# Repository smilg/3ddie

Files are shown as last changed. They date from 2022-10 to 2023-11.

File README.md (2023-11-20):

# 3ddie
3D Digital Interface, EPIC!

## Project Structure
[3ddie/](3ddie/): contains the Kicad (6.x) project for 3ddie. This includes the schematic, board layout, [BOM](3ddie/3ddie-bom-cleaned.csv), symbols, and footprints.

[mcad/](mcad/): contains SOLIDWORKS assembly files for 3ddie and the beginnings of a case.

[firmware/](firmware/): contains firmware for 3ddie. Currently, this only includes the start of the I²C to USB bridge firmware for the RP2040 to allow connection between the MGC3130 and Microchip's Aurea software. The submodules in that folder are projects that we are basing this off of.

[silkscreen_images/](silkscreen_images/): contains the image files for the silkscreen art on the PCB. These were converted to footprints using Kicad's built-in tool.

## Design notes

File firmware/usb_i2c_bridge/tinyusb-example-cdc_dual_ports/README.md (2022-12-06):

This is example code from the [TinyUSB project](https://github.com/hathach/tinyusb) created by hathach. It's located in [/examples/device/cdc_dual_ports](https://github.com/hathach/tinyusb/tree/master/examples/device/cdc_dual_ports).

It should be useful for seeing how to create our own CDC driver for communicating with Aurea.

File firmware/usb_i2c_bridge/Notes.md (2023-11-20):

# I/O Pin Setup
|Name |GPIO #|Pkg #|Config |
|:---:|:----:|:---:|:---:|
|MCLR |29 |41 |Out PU |
|TS (EIO0)|14 |17 |In/Out |
|SDA (SI0)|12 |15 |I2C_SDA (i2c0)|
|SCL (SI1)|13 |16 |I2C_SCL (i2c0)|

# rp2040 i2c interface notes
## functions
### int main(void): setup stuff
* call board_init() - pico SDK function
* call tusb_init() - for tinyusb stuff
* set gpio pin modes, initialize i2c
* infinite loop tud_task() - for tinyusb

### void tud_mount_cb(void): invoked when device is mounted
* empty

### void tud_umount_cb(void): invoked when device is unmounted
* empty

### void tud_suspend_cb(bool remote_wakeup_en): invoked when usb bus is suspended
* empty

### void tud_resume_cb(void): invoked when usb bus is resumed
* empty

# gestic.c notes

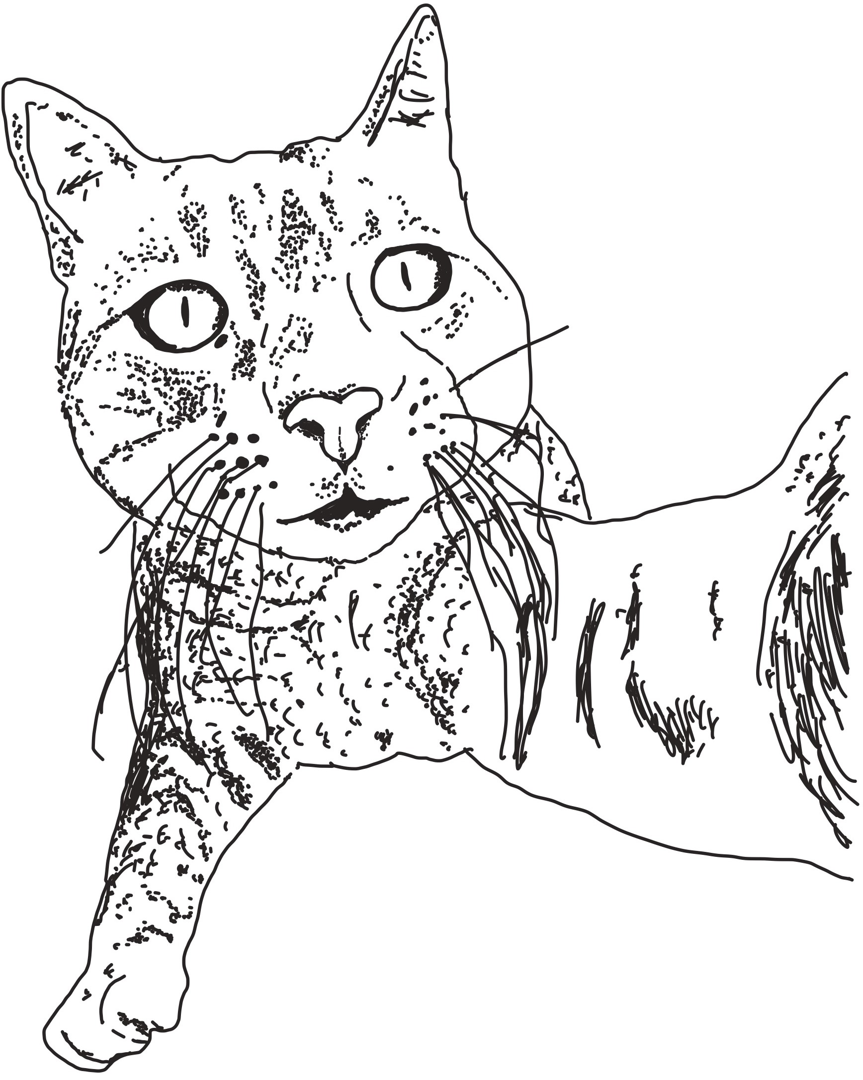
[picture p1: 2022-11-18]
silkscreen_images/cat_crop.JPG

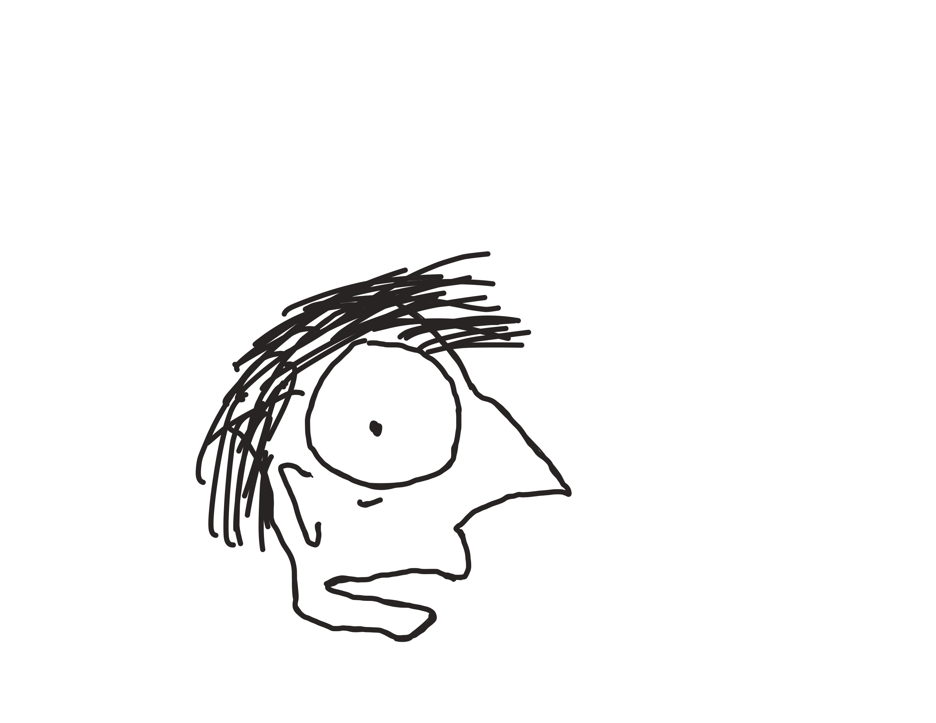
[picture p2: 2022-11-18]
silkscreen_images/grant.JPG

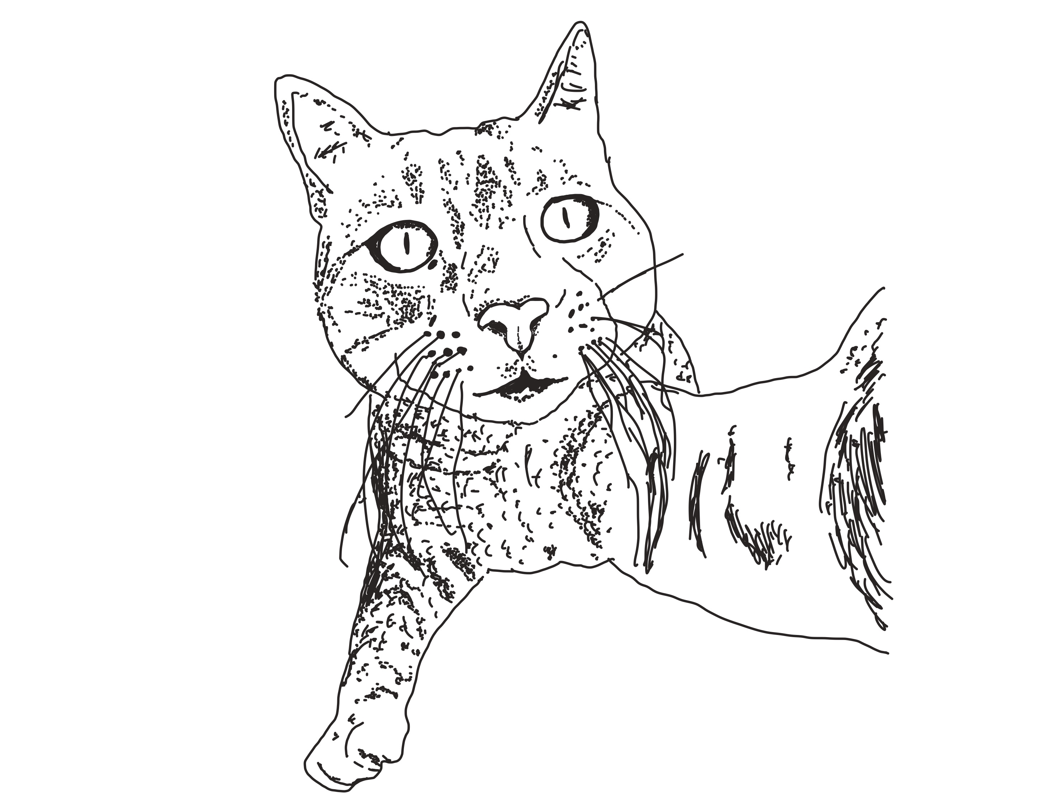
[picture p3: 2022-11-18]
silkscreen_images/cat.JPG

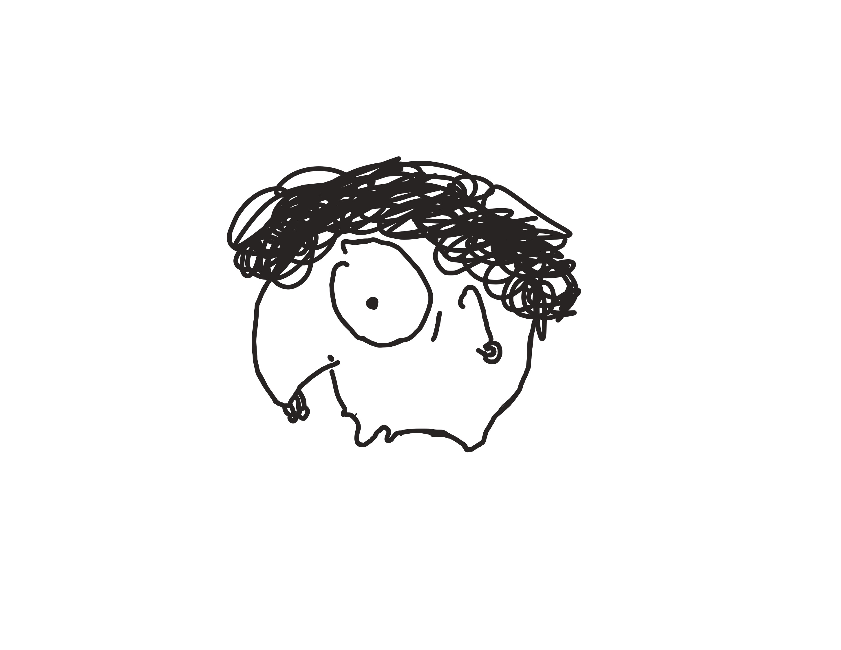
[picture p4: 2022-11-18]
silkscreen_images/max.JPG

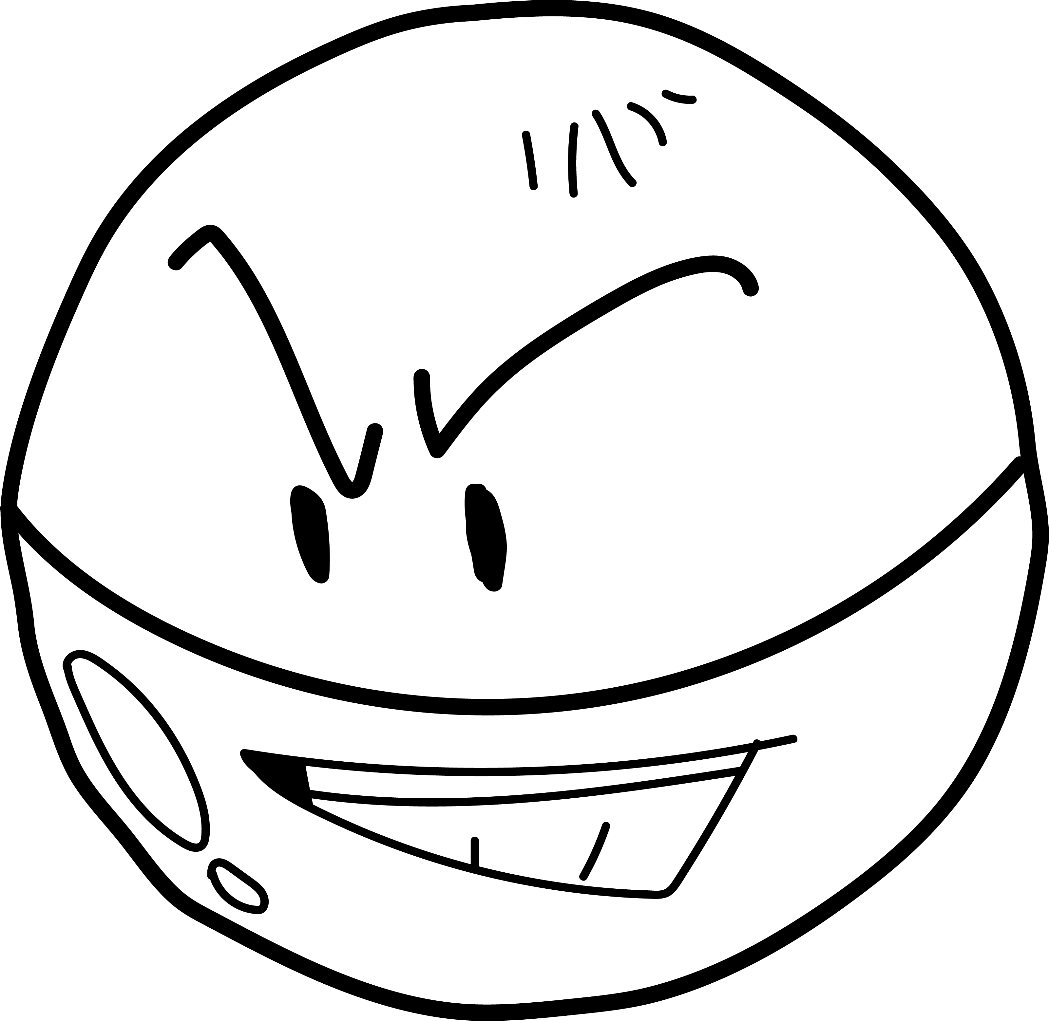
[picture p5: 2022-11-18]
silkscreen_images/electrode.png

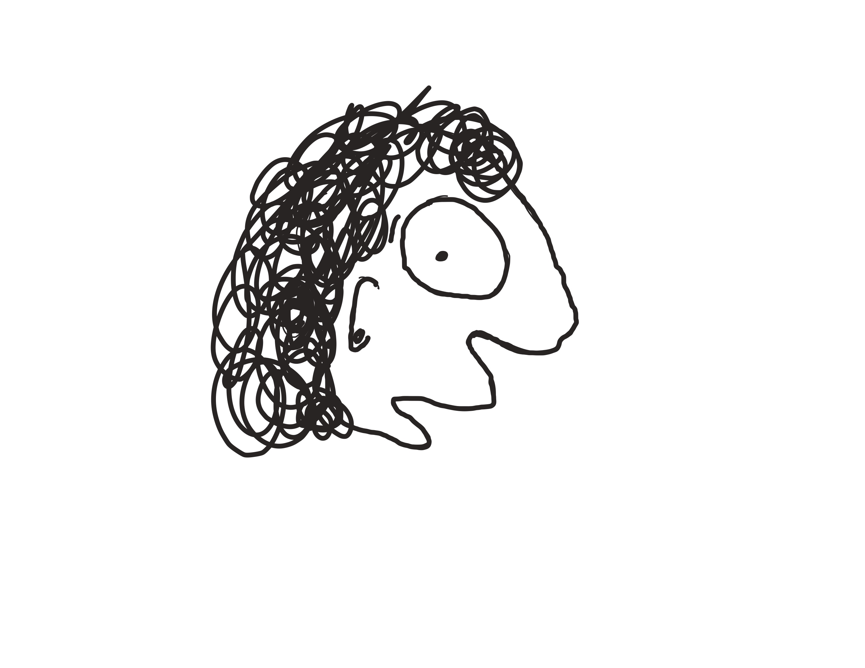
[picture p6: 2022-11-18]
silkscreen_images/smilg.JPG

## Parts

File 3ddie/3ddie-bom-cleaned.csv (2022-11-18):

Collated Components:
Item | Qty | Reference(s) | Value | Digikey Catalog # | Manufacturer Part # | MP3 Part | LibPart | Footprint | Datasheet
1 | 3 | C1, C14, C18 | 0.1?F | 1276-1033-1-ND | CL10B104JB8NNNC | Y | Device:C | Capacitor_SMD:C_0603_1608Metric | ~
2 | 8 | C2, C3, C4, C5, C6, C7, C10, C11 | 0.1?F | 1292-1366-1-ND | 0402X104K500CT | Y | Device:C | Capacitor_SMD:C_0402_1005Metric | ~
3 | 2 | C8, C9 | 1.0?F | 1276-6796-1-ND | CL05A105KL5NRNC | Y | Device:C | Capacitor_SMD:C_0402_1005Metric | ~
4 | 2 | C12, C13 | 10µF | 490-18214-1-ND | GRM188R61E106KA73D | Y | Device:C | Capacitor_SMD:C_0603_1608Metric | ~
5 | 1 | C15 | 2.2?F | 490-10731-1-ND | GRM188R61E225KA12D | N | Device:C | Capacitor_SMD:C_0603_1608Metric | ~
6 | 2 | C16, C17 | 4.7?F | 490-7203-1-ND | GRM188R61E475KE11D | N | Device:C | Capacitor_SMD:C_0603_1608Metric | ~
7 | 1 | C19 | 1.0?F | 1276-1184-1-ND | CL10B105KA8NNNC | Y | Device:C_Small | Capacitor_SMD:C_0603_1608Metric | ~
8 | 1 | C20 | 0.1?F | 1276-1033-1-ND | CL10B104JB8NNNC | Y | Device:C_Small | Capacitor_SMD:C_0603_1608Metric | ~
9 | 1 | D1 | LED | 160-1887-1-ND | LTST-C170TGKT | Y | Device:LED_Filled | LED_SMD:LED_0805_2012Metric | ~
10 | 1 | D2 | PWR | 160-1427-1-ND | LTST-C171KRKT | Y | Device:LED_Filled | LED_SMD:LED_0805_2012Metric | ~
11 | 1 | D3 | 1N4148WT | 1N4148WTCT-ND | 1N4148WT | N | Diode:1N4148WT | Diode_SMD:D_SOD-523 | https://rocelec.widen.net/view/pdf/bnxdzepaue/ONSM-S-A0003584797-1.pdf?t.download=true&u=5oefqw
12 | 1 | J1 | USB4105-GF-A | 2073-USB4105-GF-ACT-ND | USB4105-GF-A | Y | Eclectronics:USB4105-GF-A | Eclectronics:USB4105-GF-A
13 | 1 | J2 | TRS_MIDI_IN | CP1-3533NG-ND | SJ1-3533NG | N | Connector:AudioJack3 | Connector_Audio:Jack_3.5mm_CUI_SJ1-3533NG_Horizontal | https://www.cuidevices.com/product/resource/sj1-353xng.pdf
14 | 1 | J3 | TRS_MIDI_OUT | CP1-3533NG-ND | SJ1-3533NG | N | Connector:AudioJack3 | Connector_Audio:Jack_3.5mm_CUI_SJ1-3533NG_Horizontal | https://www.cuidevices.com/product/resource/sj1-353xng.pdf
15 | 1 | J4 | Conn_02x15_Odd_Even | 2057-BHR-30-HUA-ND | BHR-30-HUA | N | Connector_Generic:Conn_02x15_Odd_Even | Connector_IDC:IDC-Header_2x15_P2.54mm_Horizontal | https://app.adam-tech.com/products/download/data_sheet/203217/bhr-xx-hua-data-sheet.pdf
16 | 4 | R1, R2, R3, R4 | 5.1K? | P5.10KHCT-ND | ERJ-3EKF5101V | Y | Device:R | Resistor_SMD:R_0603_1608Metric | ~
17 | 2 | R5, R6 | 27? | P27.0LCT-ND | ERJ-2RKF27R0X | Y | Device:R | Resistor_SMD:R_0402_1005Metric | ~
18 | 2 | R7, R12 | 1K? | 311-1.00KHRCT-ND | RC0603FR-071KL | Y | Device:R | Resistor_SMD:R_0603_1608Metric | ~
19 | 5 | R8, R9, R10, R11, R13 | 10K? | CR0603-FX-1002ELFCT-ND | CR0603-FX-1002ELF | N | Device:R | Resistor_SMD:R_0603_1608Metric | ~
20 | 2 | R14, R15 | 1.8K? | 311-1.80KHRCT-ND | RC0603FR-071K8L | N | Device:R | Resistor_SMD:R_0603_1608Metric | ~
21 | 1 | R16 | 220? | 311-220HRCT-ND | RC0603FR-07220RL | N | Device:R | Resistor_SMD:R_0603_1608Metric | ~
22 | 1 | R17 | 10? | 13-RC0603FR-1010RLCT-ND | RC0603FR-1010RL | N | Device:R | Resistor_SMD:R_0603_1608Metric | ~
23 | 1 | R18 | 33? | 311-33.0HRCT-ND | RC0603FR-0733RL | N | Device:R | Resistor_SMD:R_0603_1608Metric | ~
24 | 1 | R19 | 4.7K? | 311-4.70KHRCT-ND | RC0603FR-074K7L | N | Device:R_Small | Resistor_SMD:R_0603_1608Metric | ~
25 | 2 | RV1, RV2 | 10K | PDB12-H4251-103BF-ND | PDB12-H4251-103BF | N | Device:R_Potentiometer | 3ddie:PDB12-H4251-103BF | https://www.bourns.com/docs/Product-Datasheets/PDB12.pdf
26 | 1 | S1 | RST | EG4374CT-ND | TL3301AF160QJ | Y | Eclectronics:SW | Eclectronics:TL3301AFxxxxJ | https://www.ckswitches.com/media/1465/kxt3.pdf
27 | 1 | S2 | BOOT | EG4374CT-ND | TL3301AF160QJ | Y | Eclectronics:SW | Eclectronics:TL3301AFxxxxJ | https://www.ckswitches.com/media/1465/kxt3.pdf
28 | 1 | U1 | W25Q128JV | W25Q128JVPIMCT-ND | W25Q128JVPIM TR | Y | Eclectronics:W25Q128JV | Eclectronics:MIC_WSON-8 | https://www.winbond.com/resource-files/w25q128jv_dtr%20revc%2003272018%20plus.pdf
29 | 1 | U2 | RP2040 | 2648-SC0914(13)CT-ND | SC0914(13) | Y | Eclectronics:RP2040 | Eclectronics:RP2040 | https://datasheets.raspberrypi.com/rp2040/rp2040-datasheet.pdf
30 | 1 | U3 | MCP1702T-3302E_CB | MCP1702T-3302E/CBCT-ND | MCP1702T-3302E/CB | Y | Eclectronics:MCP1702T-3302E_CB | Package_TO_SOT_SMD:SOT-23 | https://ww1.microchip.com/downloads/en/DeviceDoc/22008E.pdf
31 | 1 | U4 | MGC3130-I/MQ | MGC3130-I/MQ-ND | MGC3130-I/MQ | N | :MGC3130-I{brace}slash}MQ_1 | 3ddie:MGC3130T-I_MQ | https://ww1.microchip.com/downloads/en/DeviceDoc/MGC3030-3130-3D-Tracking-and-Gesture-Controller-40001667F.pdf
32 | 1 | U5 | MCP1416R | MCP1416RT-E/OTCT-ND | MCP1416RT-E/OT | N | Driver_FET:MCP1416R | Package_TO_SOT_SMD:SOT-23-5 | http://ww1.microchip.com/downloads/en/DeviceDoc/20002092F.pdf
33 | 1 | U6 | 6N137 | 6N137SM-ND | 6N137SM | N | Isolator:6N137 | 3ddie:6N137_Leadbend | https://rocelec.widen.net/view/pdf/zs07d29frw/ONSM-S-A0003591003-1.pdf?t.download=true&u=5oefqw
34 | 1 | Y1 | 12MHz | 490-17944-1-ND | CSTNE12M0G55A000R0 | Y | Eclectronics:Crystal | Eclectronics:CSTNE | https://www.murata.com/en/products/productdata/8801162002462/SPEC-CSTNE12M0G55A000R0.pdf

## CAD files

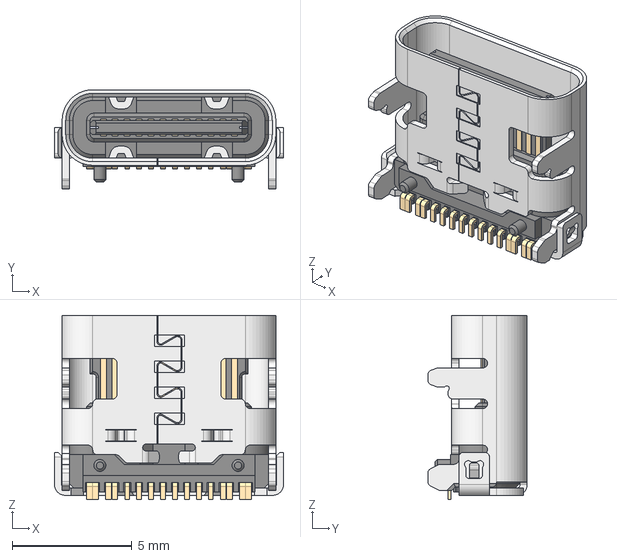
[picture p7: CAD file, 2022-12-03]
3ddie/Eclectronics/3dshapes/USB4105-GF-A.step
9.58 x 4.16 x 7.71 mm

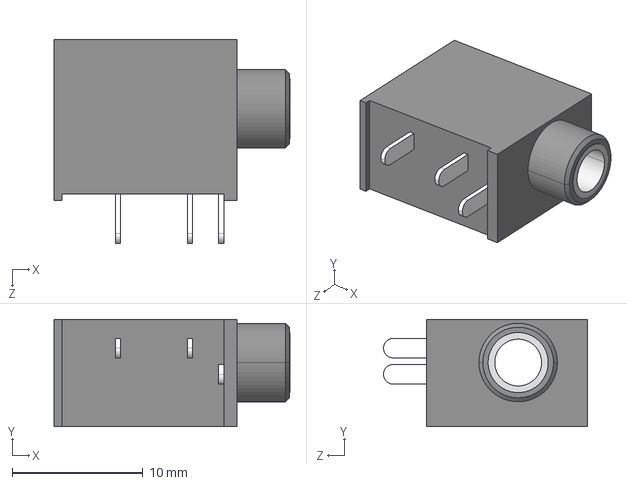
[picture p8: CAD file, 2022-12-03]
3ddie/3ddie_symbols/3dmodels/CUI_DEVICES_SJ1-3533NG.step
18.1 x 8.20 x 15.6 mm

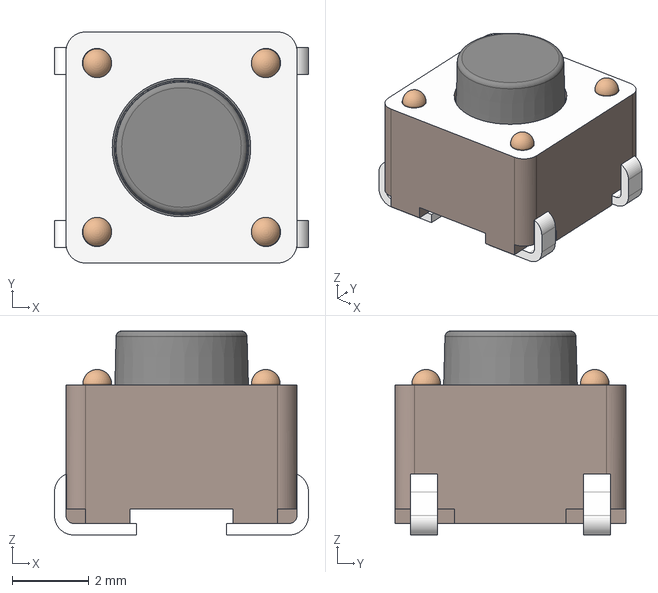
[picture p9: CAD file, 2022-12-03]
3ddie/Eclectronics/3dshapes/TL3301AFxxxxJ.stp
6.60 x 6.00 x 5.30 mm

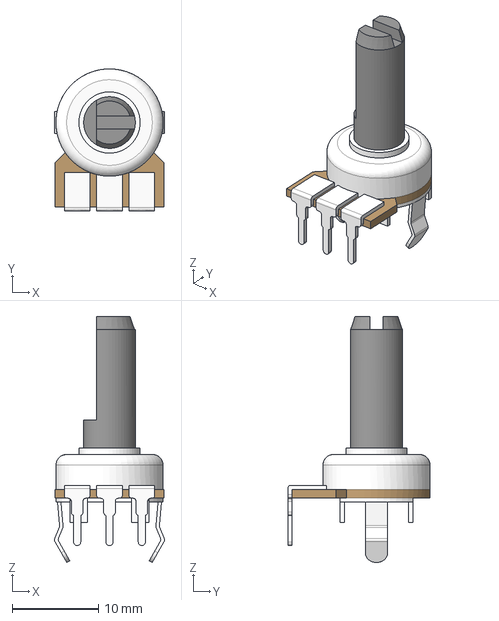
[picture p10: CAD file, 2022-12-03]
3ddie/3ddie_symbols/3dmodels/PDB12-H4251-103PF.step
12.8 x 16.5 x 28.5 mm

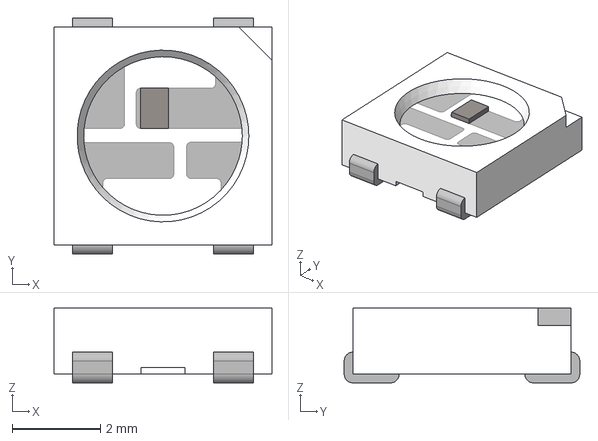
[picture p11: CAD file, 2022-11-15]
3ddie/Eclectronics/3dshapes/WS2812_RGB_LED_updated.stp
4.95 x 5.35 x 1.70 mm

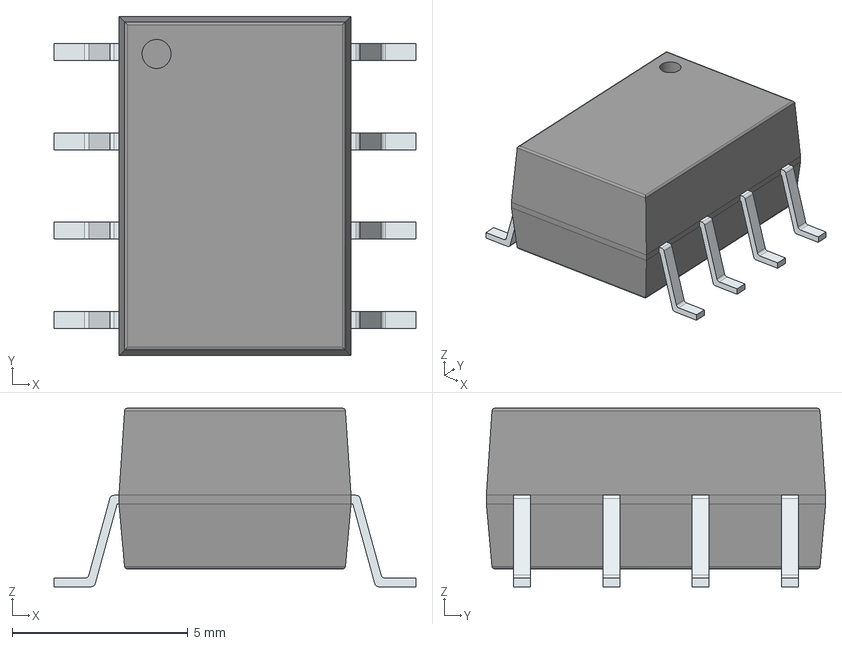
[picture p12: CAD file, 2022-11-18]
3ddie/3ddie_symbols/3dmodels/6N137SDM.stp
10.3 x 9.65 x 5.08 mm
PinsArrayLR

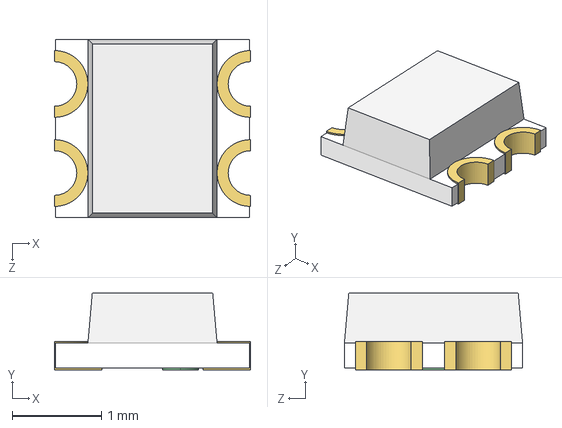
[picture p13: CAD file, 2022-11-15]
3ddie/Eclectronics/3dshapes/WS2812-2020.STEP
2.20 x 0.86 x 2.00 mm

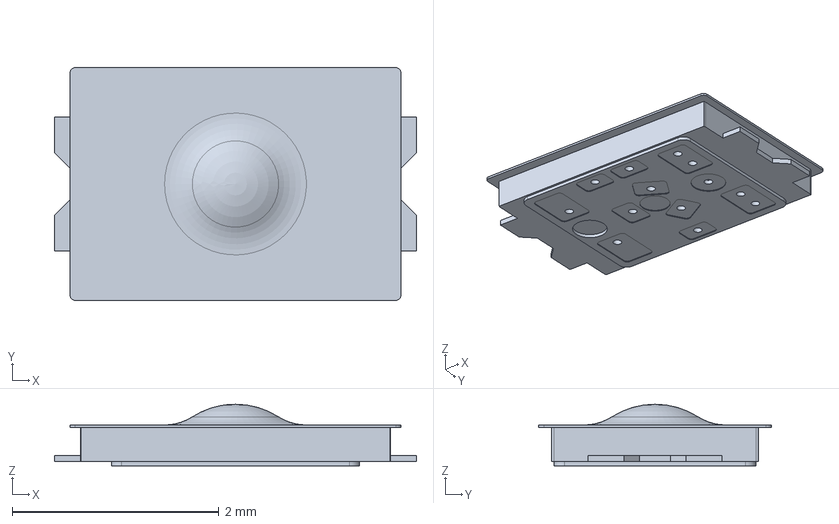
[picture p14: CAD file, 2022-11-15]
3ddie/Eclectronics/3dshapes/KXT321LHS.stp
3.50 x 2.25 x 0.595 mm

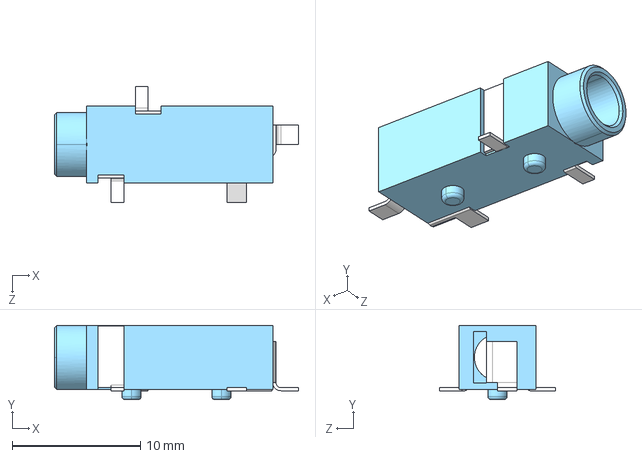
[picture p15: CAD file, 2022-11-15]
3ddie/Eclectronics/3dshapes/SJ-3524-SMT-TR-BE.step
19.0 x 5.80 x 9.00 mm

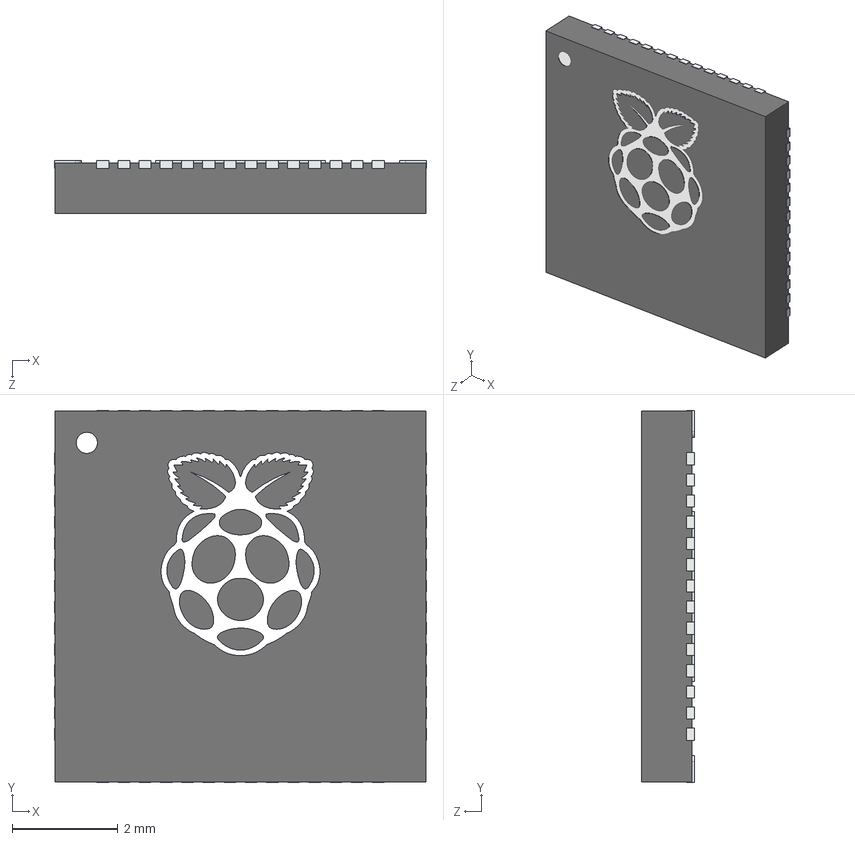
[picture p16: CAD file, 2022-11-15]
3ddie/Eclectronics/3dshapes/RP2040_QFN_PACKAGE.STEP
7.02 x 7.02 x 1.00 mm

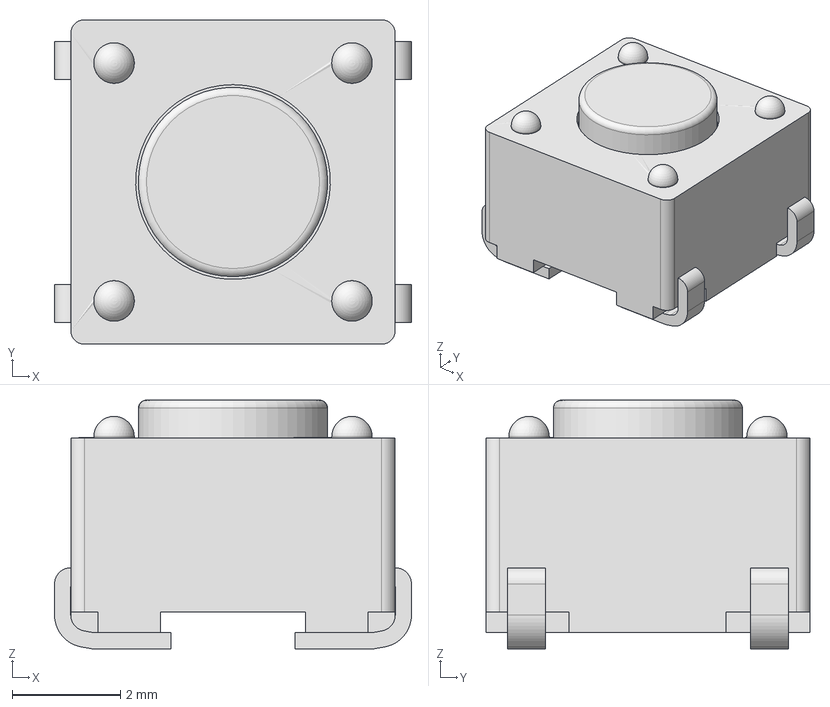
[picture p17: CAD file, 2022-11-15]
3ddie/Eclectronics/3dshapes/TL3301NFxxxxJ.stp
6.60 x 6.00 x 4.60 mm

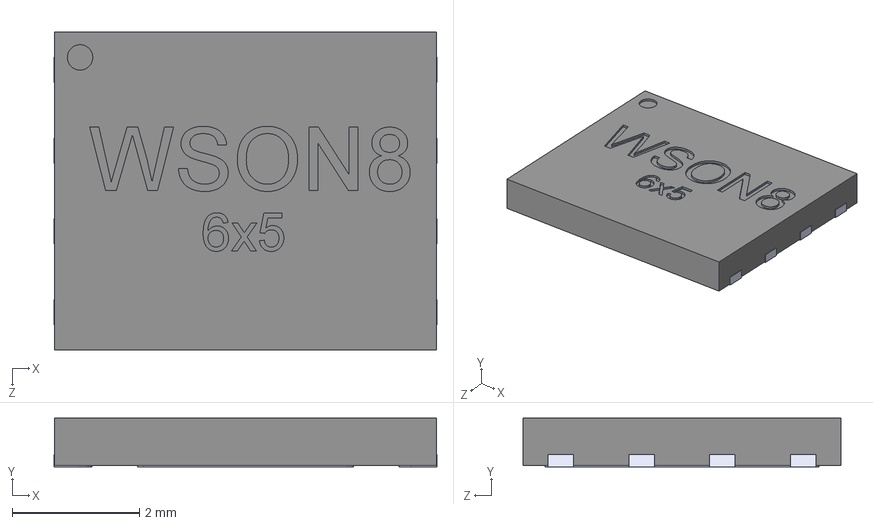
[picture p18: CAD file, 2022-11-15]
3ddie/Eclectronics/3dshapes/WSON8-6x5.STEP
6.02 x 0.77 x 5.00 mm

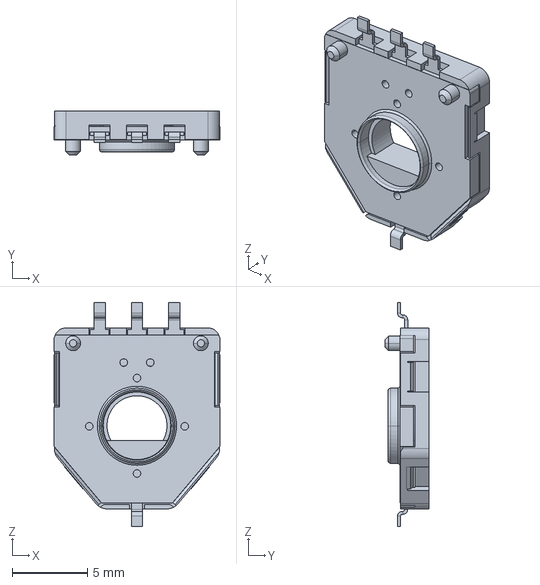
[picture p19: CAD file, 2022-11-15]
3ddie/Eclectronics/3dshapes/3382g-001-xxx.stp
11.0 x 2.95 x 14.9 mm

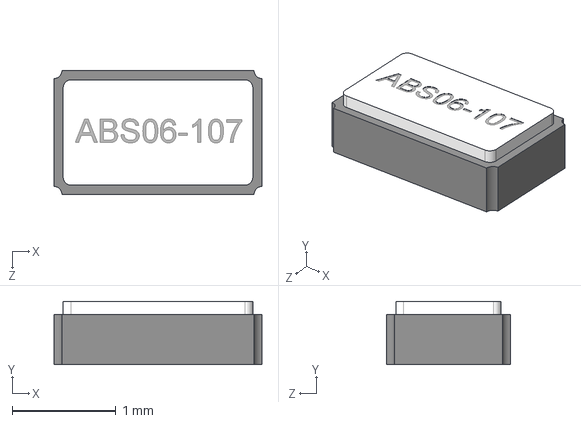
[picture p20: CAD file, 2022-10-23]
3ddie/Eclectronics/3dshapes/ABS06-107.STP
2.01 x 0.612 x 1.19 mm

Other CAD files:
3ddie/Eclectronics/3dshapes/CUI_SDS-50J.step
3ddie/Eclectronics/3dshapes/ABM10.STP
3ddie/Eclectronics/3dshapes/RNR0011A.stp
3ddie/3ddie_symbols/3dmodels/10112684-G03-06ULFc.igs
3ddie/Eclectronics/3dshapes/CSTNE.step
3ddie/Eclectronics/3dshapes/DFN-8-3x3-0_5.STEP
3ddie/Eclectronics/3dshapes/DFN8_3x3_0.65.step
3ddie/Eclectronics/3dshapes/PA5003.182NLT.step
3ddie/Eclectronics/3dshapes/QFN-32_5x5.stp
3ddie/Eclectronics/3dshapes/S4B-PH-SM4-TB.stp
3ddie/Eclectronics/3dshapes/UFQFPN48.stp

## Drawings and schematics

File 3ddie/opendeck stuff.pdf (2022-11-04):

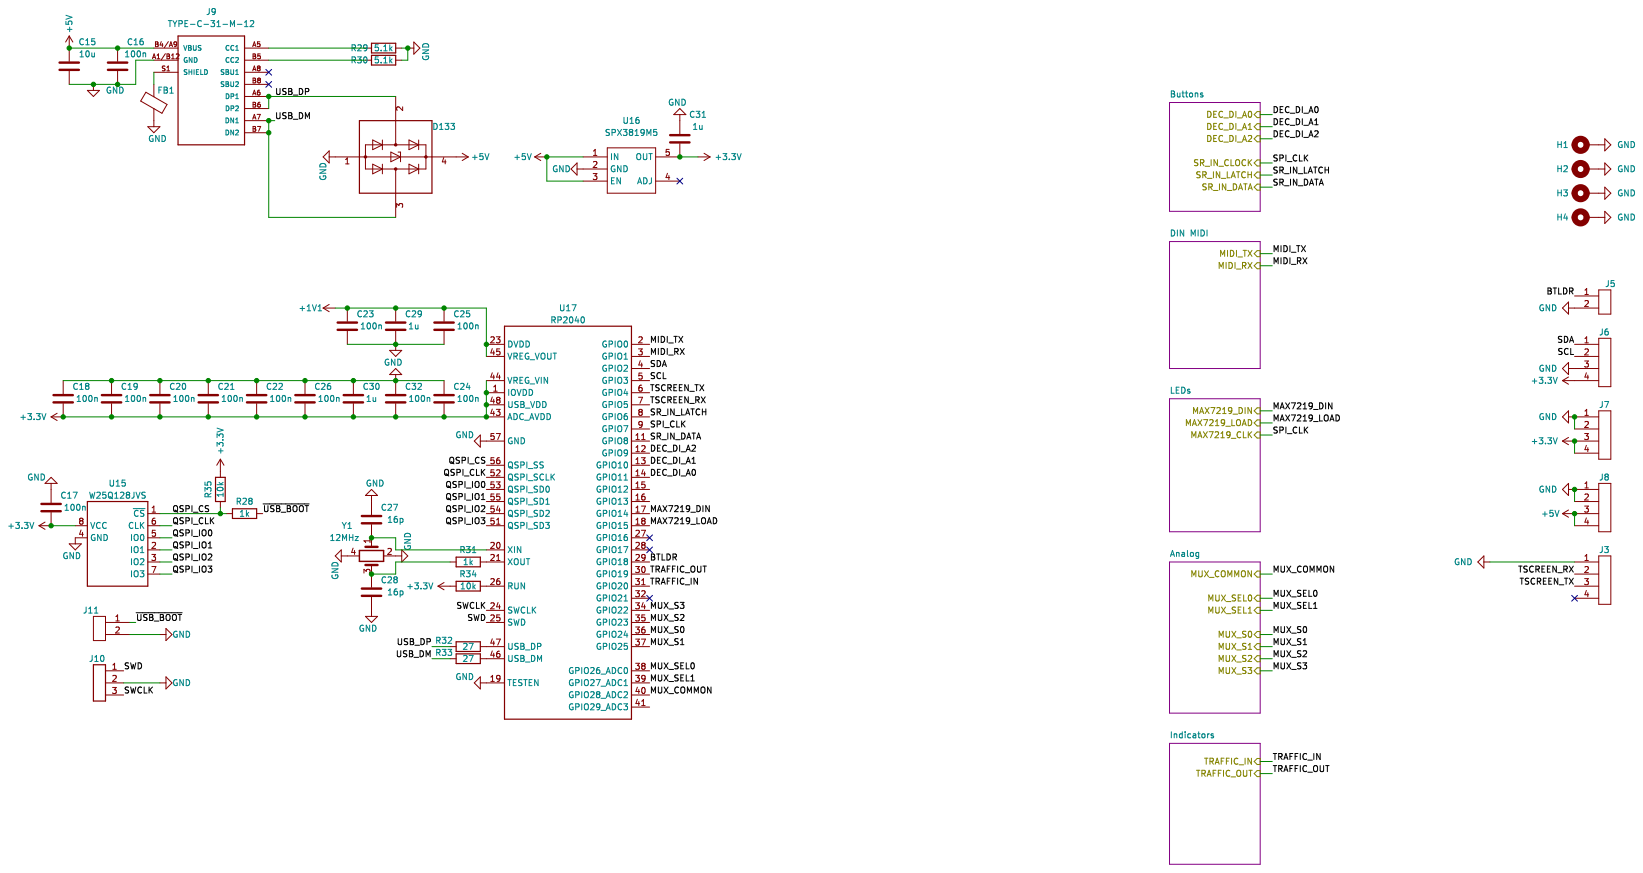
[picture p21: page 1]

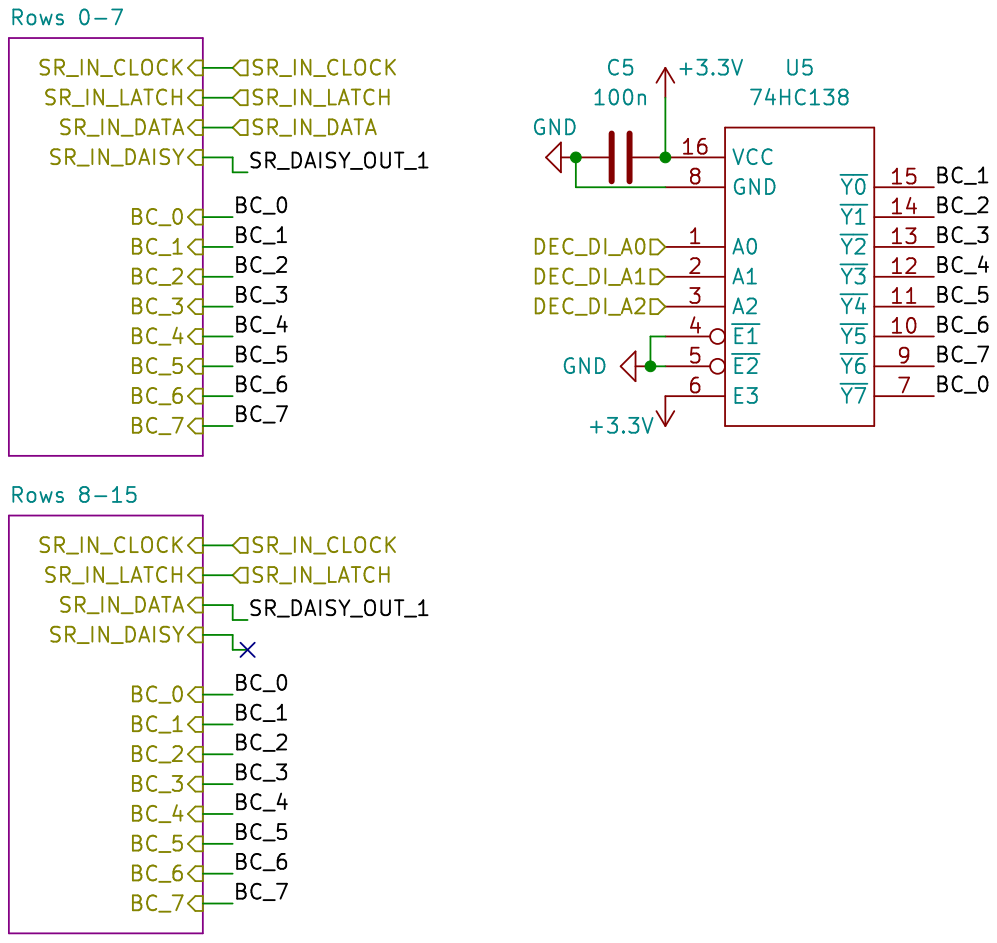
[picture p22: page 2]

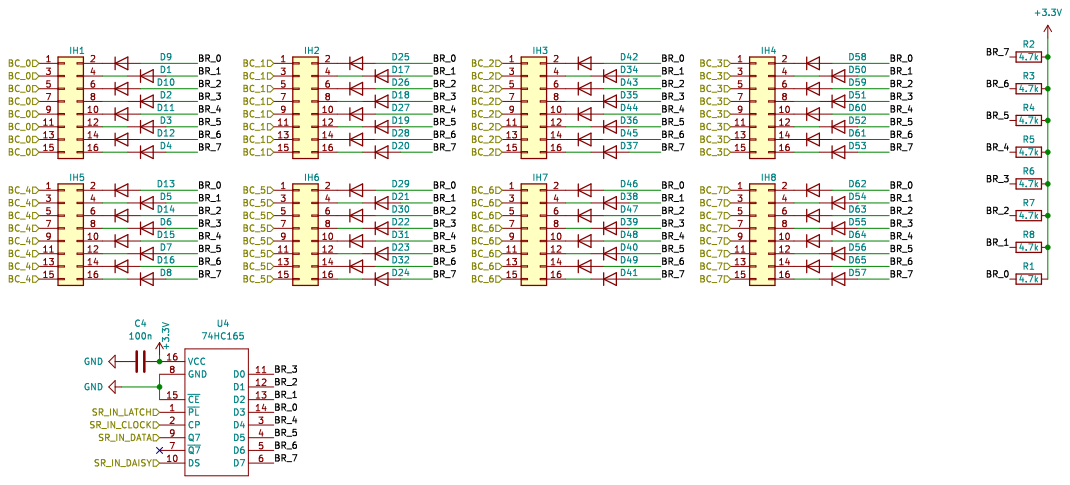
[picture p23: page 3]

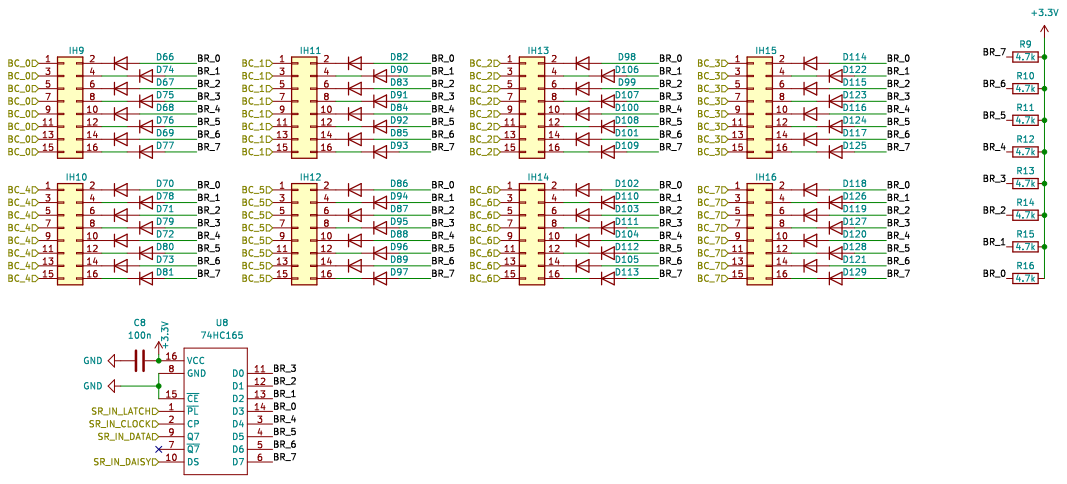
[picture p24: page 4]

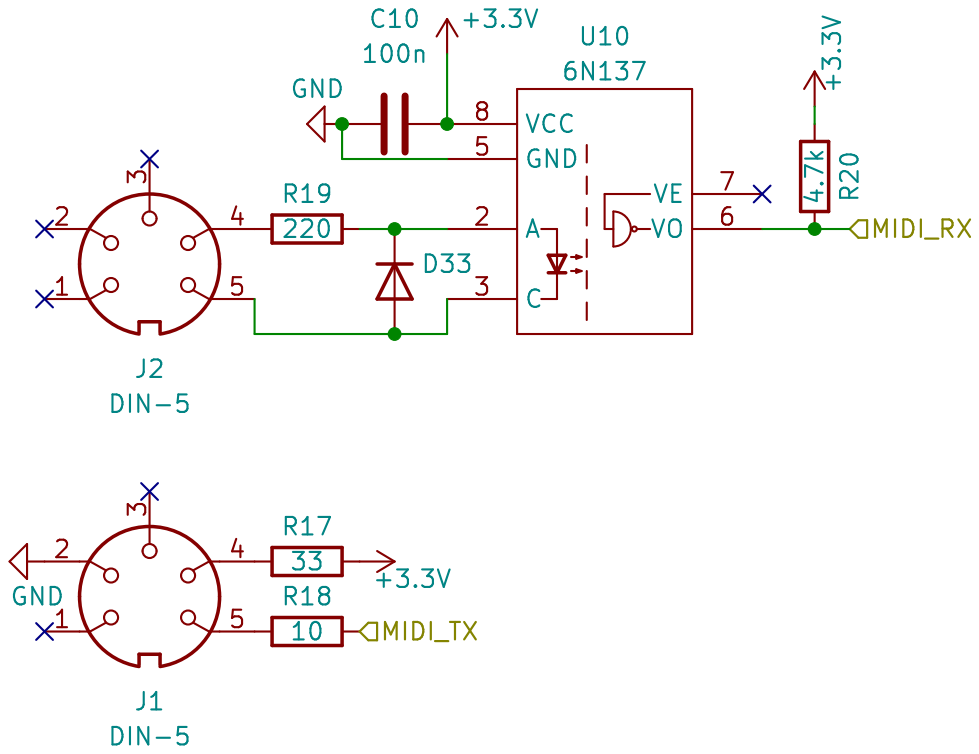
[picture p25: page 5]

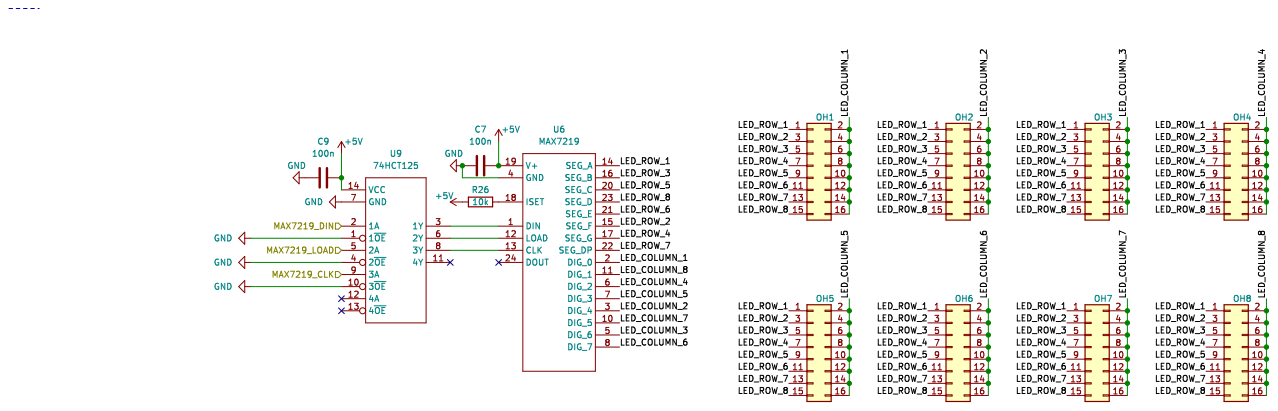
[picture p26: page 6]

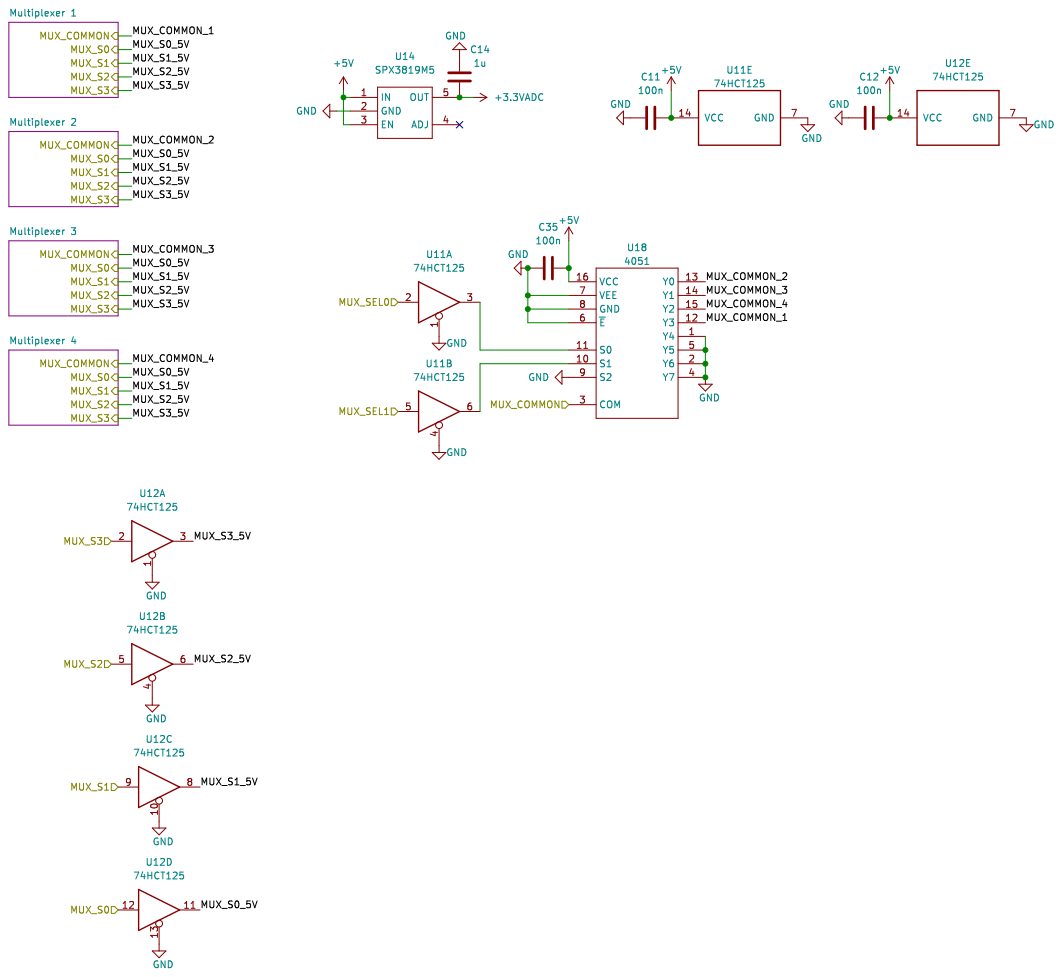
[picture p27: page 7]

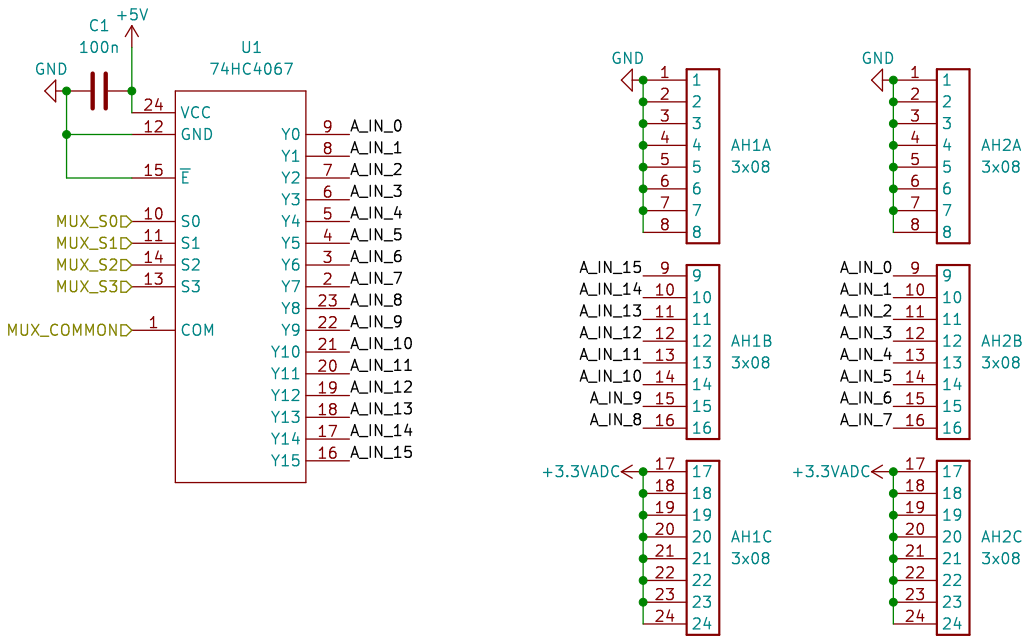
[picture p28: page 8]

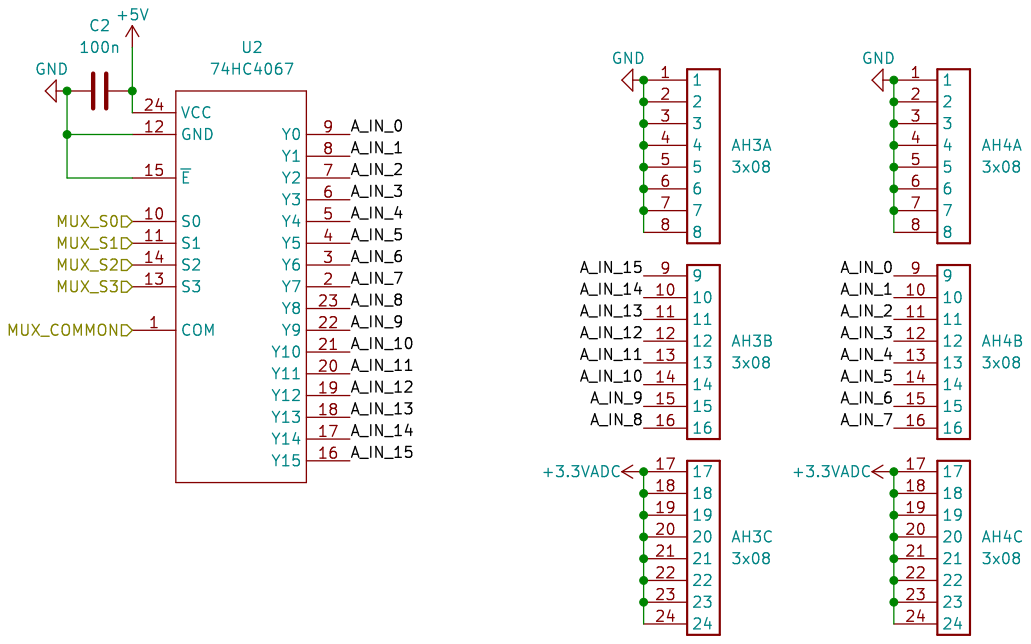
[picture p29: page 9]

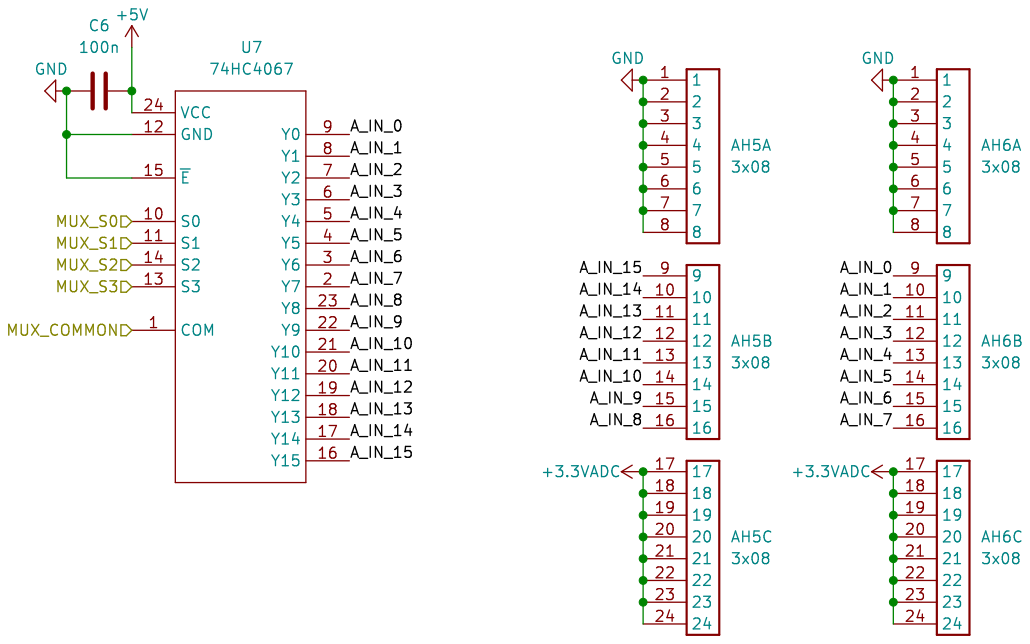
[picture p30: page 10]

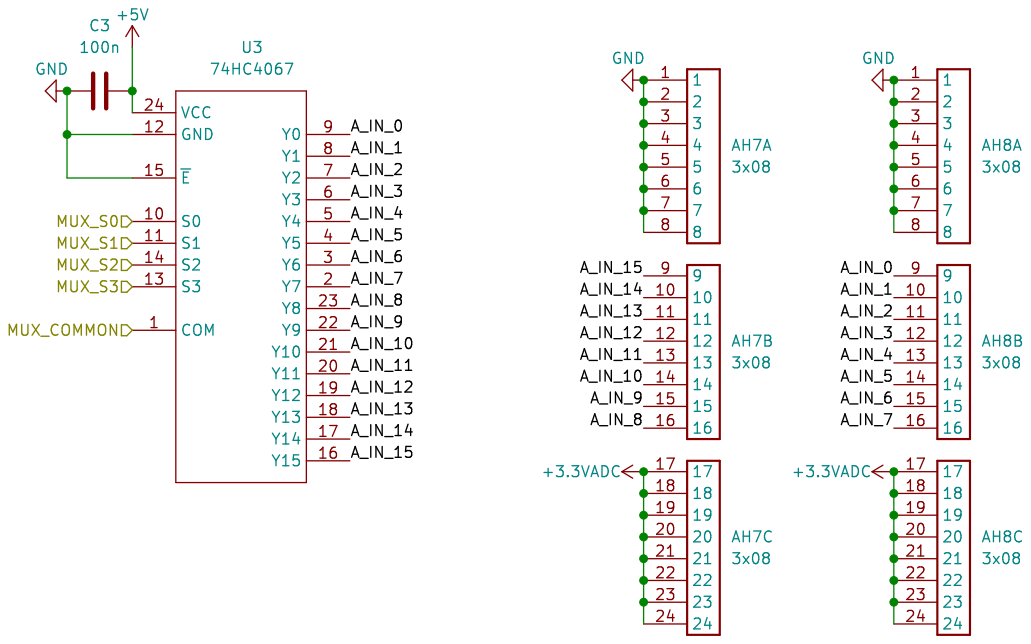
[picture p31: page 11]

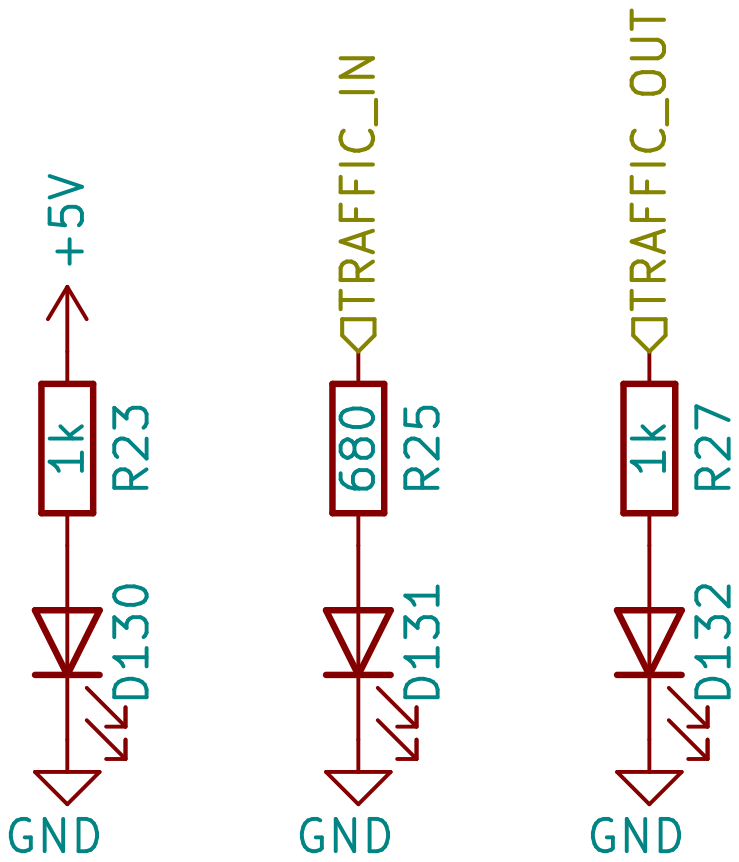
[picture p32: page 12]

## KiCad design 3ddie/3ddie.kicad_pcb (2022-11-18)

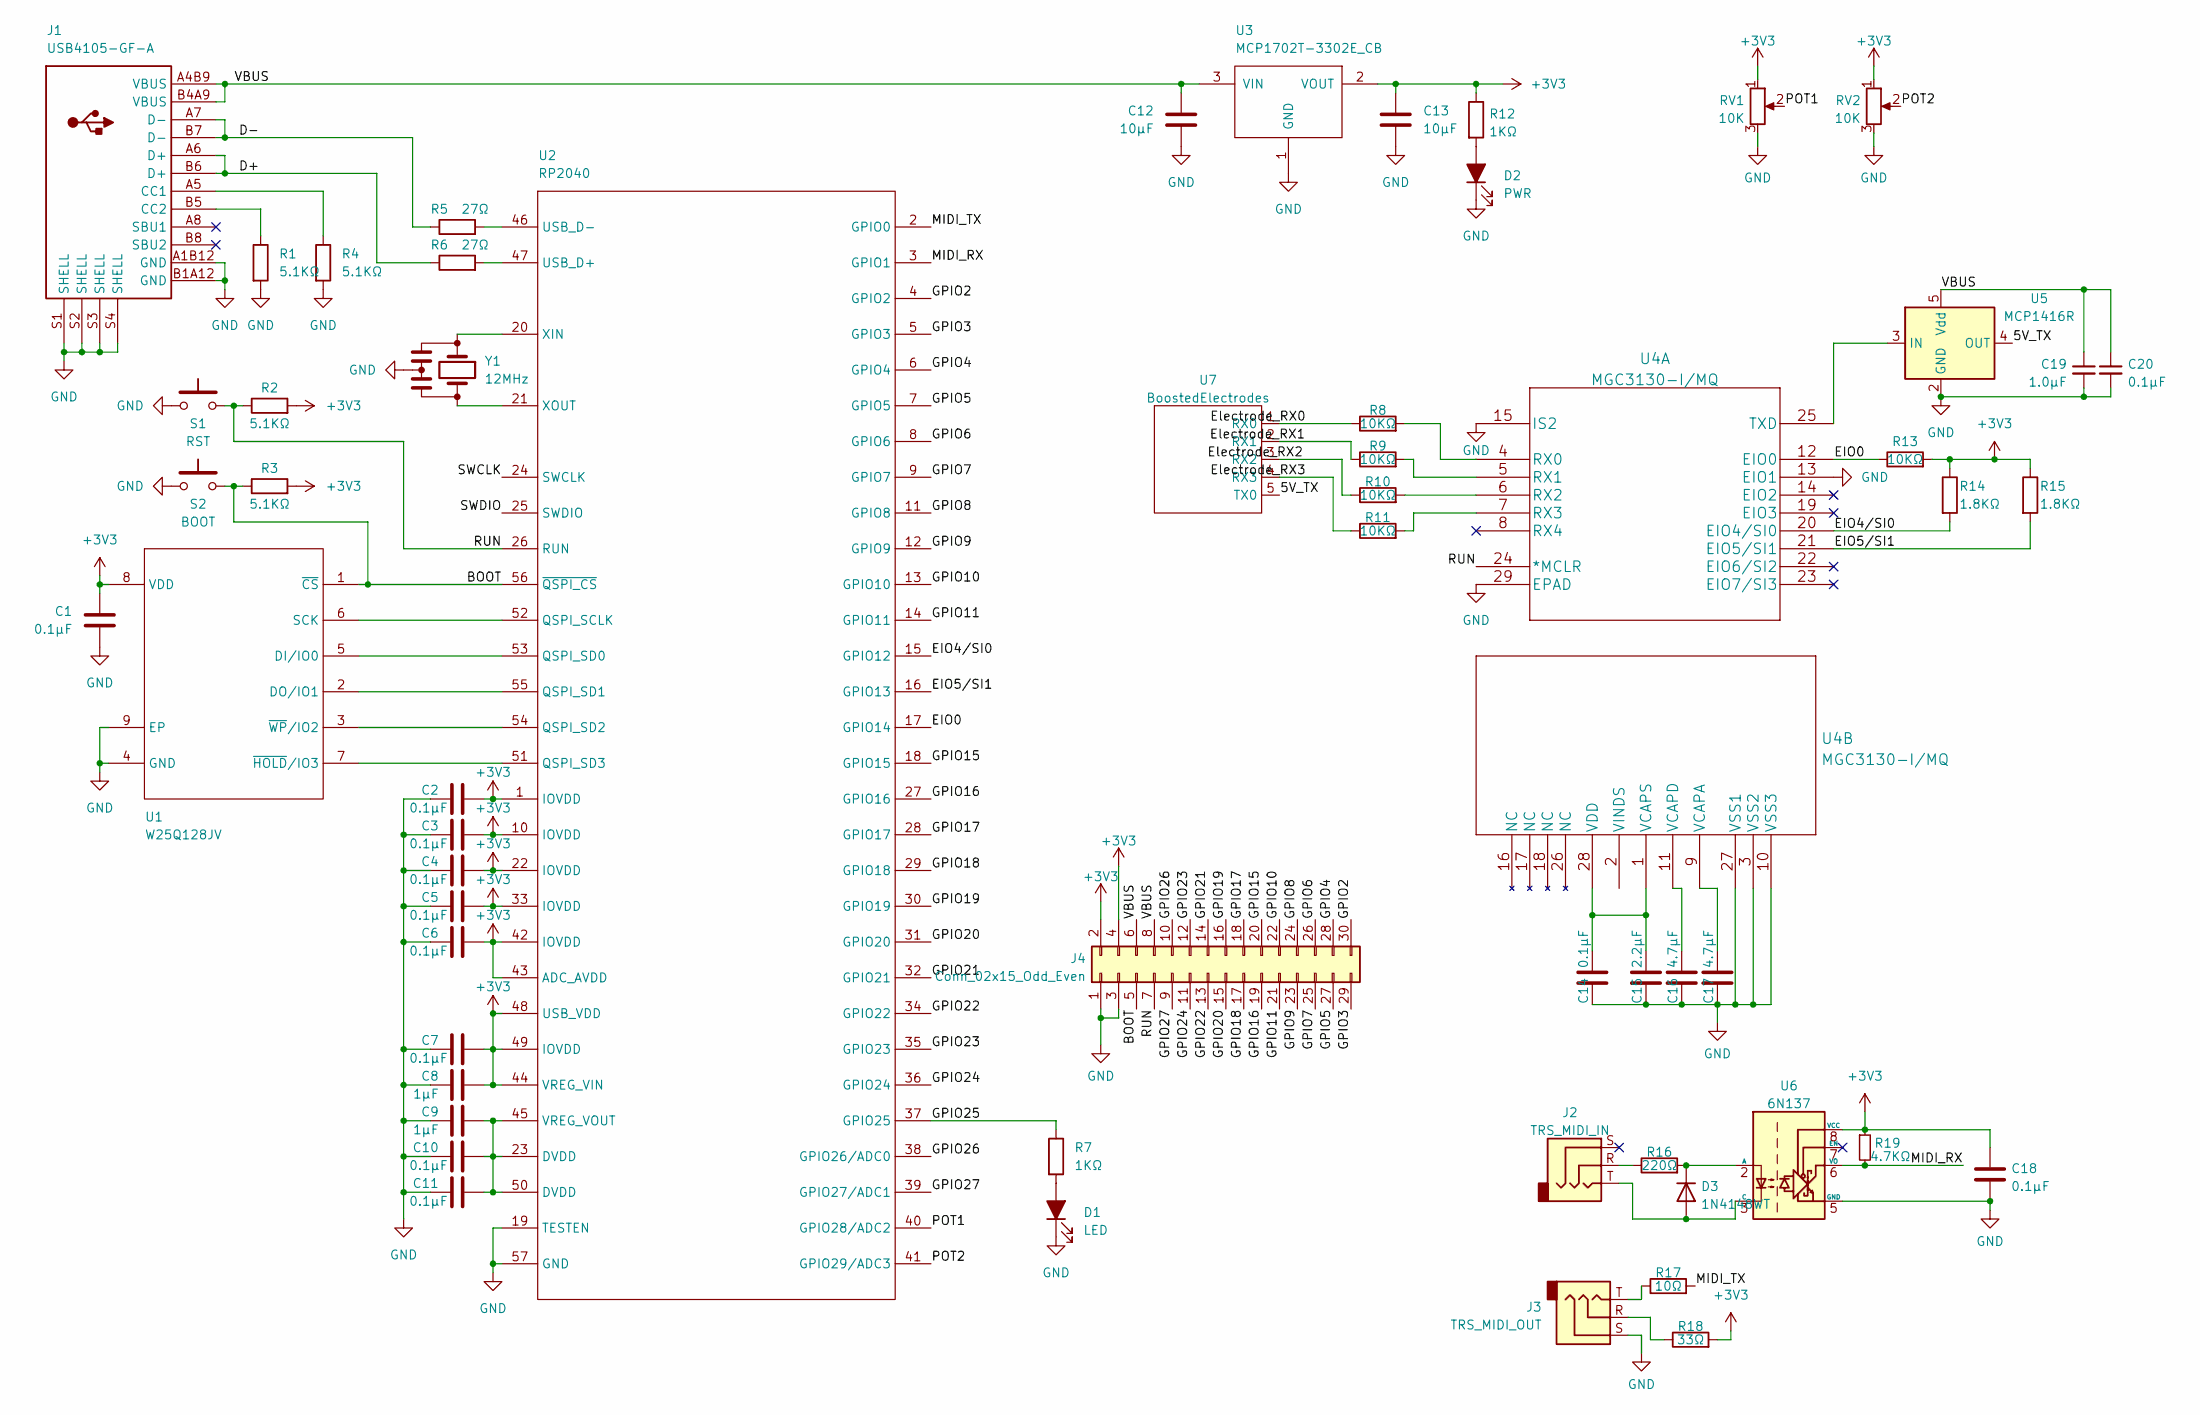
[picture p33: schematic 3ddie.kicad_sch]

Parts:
C1: 0.1µF; C_0603_1608Metric
C2, C3, C4, C5, C6, C7, C10, C11: 0.1µF; C_0402_1005Metric
C8, C9: 1µF; C_0402_1005Metric
C12, C13: 10µF; C_0603_1608Metric
C14, C18, C20: 0.1μF; C_0603_1608Metric
C15: 2.2μF; C_0603_1608Metric
C16, C17: 4.7μF; C_0603_1608Metric
C19: 1.0μF; C_0603_1608Metric
D1: LED; LED_0805_2012Metric; Digikey Catalog # 160-1887-1-ND
D2: PWR; LED_0805_2012Metric; Digikey Catalog # 160-1427-1-ND
D3: 1N4148WT; D_SOD-523; Manufacturer Part # 1N4148WT; Digikey Catalog # 1N4148WTCT-ND
J1: USB4105-GF-A; Manufacturer Part # USB4105-GF-A; Digikey Catalog # 2073-USB4105-GF-ACT-ND
J2: TRS_MIDI_IN; Jack_3.5mm_CUI_SJ1-3533NG_Horizontal; Manufacturer Part # SJ1-3533NG; Digikey Catalog # CP1-3533NG-ND
J3: TRS_MIDI_OUT; Jack_3.5mm_CUI_SJ1-3533NG_Horizontal; Manufacturer Part # SJ1-3533NG; Digikey Catalog # CP1-3533NG-ND
J4: Conn_02x15_Odd_Even; IDC-Header_2x15_P2.54mm_Horizontal
R1, R2, R3, R4: 5.1KΩ; R_0603_1608Metric
R5, R6: 27Ω; R_0402_1005Metric
R7, R12: 1KΩ; R_0603_1608Metric
R8, R9, R10, R11, R13: 10KΩ; R_0603_1608Metric
R14, R15: 1.8KΩ; R_0603_1608Metric
R16: 220Ω; R_0603_1608Metric
R17: 10Ω; R_0603_1608Metric
R18: 33Ω; R_0603_1608Metric
R19: 4.7KΩ; R_0603_1608Metric
RV1, RV2: 10K; PDB12-H4251-103BF
S1: RST; TL3301AFxxxxJ; Manufacturer Part # KTX 321 LHS; Digikey Catalog # CKN10778CT-ND
S2: BOOT; TL3301AFxxxxJ; Manufacturer Part # KTX 321 LHS; Digikey Catalog # CKN10778CT-ND
U1: W25Q128JV; MIC_WSON-8; Manufacturer Part # W25Q128JVPIM TR; Digikey Catalog # W25Q128JVPIMCT-ND
U2: RP2040; Manufacturer Part # SC0914(13); Digikey Catalog # 2648-SC0914(13)CT-ND
U3: MCP1702T-3302E_CB; SOT-23; Manufacturer Part # MCP1702T-3302E/CB; Digikey Catalog # MCP1702T-3302E/CBCT-ND
U4: MGC3130-I/MQ; MGC3130T-I_MQ; Manufacturer Part # MGC3130-I/MQ; Digikey Catalog # MGC3130-I/MQ-ND
U5: MCP1416R; SOT-23-5; Manufacturer Part # MCP1416RT-E/OT; Digikey Catalog # MCP1416RT-E/OTCT-ND
U6: 6N137; 6N137_Leadbend; Manufacturer Part # 6N137SM; Digikey Catalog # 6N137SM-ND
U7: BoostedElectrodes
Y1: 12MHz; CSTNE; Manufacturer Part # CSTNE12M0G55A000R0; Digikey Catalog # 490-17944-1-ND

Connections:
+3V3: C1.2, C2.1, C3.1, C4.1, C5.1, C6.1, C7.1, C8.1, C13.1, C18.1, J4.2, J4.4, R2.2, R3.2, R12.1, R13.2, R14.1, R15.1, R18.2, R19.1, RV1.1, RV2.1, U1.8 (VDD), U2.1 (IOVDD), U2.10 (IOVDD), U2.22 (IOVDD), U2.33 (IOVDD), U2.42 (IOVDD), U2.43 (ADC_AVDD), U2.44 (VREG_VIN), U2.48 (USB_VDD), U2.49 (IOVDD), U3.2 (VOUT), U6.8 (VCC)
/5V_TX: U5.4 (OUT), U7.5 (TX0)
/BOOT: J4.5, R3.1, S2.2, U1.1 (~CS), U2.56 (~QSPI_CS)
/D+: J1.A6 (D+), J1.B6 (D+), R6.1
/D-: J1.A7 (D-), J1.B7 (D-), R5.1
/EIO0: R13.1, U2.17 (GPIO14), U4.12 (EIO0)
/EIO4/SI0: R14.2, U2.15 (GPIO12), U4.20 (EIO4/SI0)
/EIO5/SI1: R15.2, U2.16 (GPIO13), U4.21 (EIO5/SI1)
/Electrode_RX0: R8.1, U7.1 (RX0)
/Electrode_RX1: R9.1, U7.2 (RX1)
/Electrode_RX2: R10.1, U7.3 (RX2)
/Electrode_RX3: R11.1, U7.4 (RX3)
/GPIO2: J4.30, U2.4 (GPIO2)
/GPIO3: J4.29, U2.5 (GPIO3)
/GPIO4: J4.28, U2.6 (GPIO4)
/GPIO5: J4.27, U2.7 (GPIO5)
/GPIO6: J4.26, U2.8 (GPIO6)
/GPIO7: J4.25, U2.9 (GPIO7)
/GPIO8: J4.24, U2.11 (GPIO8)
/GPIO9: J4.23, U2.12 (GPIO9)
/GPIO10: J4.22, U2.13 (GPIO10)
/GPIO11: J4.21, U2.14 (GPIO11)
/GPIO15: J4.20, U2.18 (GPIO15)
/GPIO16: J4.19, U2.27 (GPIO16)
/GPIO17: J4.18, U2.28 (GPIO17)
/GPIO18: J4.17, U2.29 (GPIO18)
/GPIO19: J4.16, U2.30 (GPIO19)
/GPIO20: J4.15, U2.31 (GPIO20)
/GPIO21: J4.14, U2.32 (GPIO21)
/GPIO22: J4.13, U2.34 (GPIO22)
/GPIO23: J4.12, U2.35 (GPIO23)
/GPIO24: J4.11, U2.36 (GPIO24)
/GPIO25: R7.1, U2.37 (GPIO25)
/GPIO26: J4.10, U2.38 (GPIO26/ADC0)
/GPIO27: J4.9, U2.39 (GPIO27/ADC1)
/MIDI_RX: R19.2, U2.3 (GPIO1), U6.6 (VO)
/MIDI_TX: R17.2, U2.2 (GPIO0)
/POT1: RV1.2, U2.40 (GPIO28/ADC2)
/POT2: RV2.2, U2.41 (GPIO29/ADC3)
/RUN: J4.7, R2.1, S1.2, U2.26 (RUN), U4.24 (*MCLR)
/SWCLK: U2.24 (SWCLK)
/SWDIO: U2.25 (SWDIO)
/VBUS: C12.2, C19.1, C20.1, J1.A4B9 (VBUS), J1.B4A9 (VBUS), J4.6, J4.8, U3.3 (VIN), U5.5 (Vdd)
GND: C1.1, C2.2, C3.2, C4.2, C5.2, C6.2, C7.2, C8.2, C9.2, C10.2, C11.2, C12.1, C13.2, C14.1, C15.1, C16.1, C17.1, C18.2, C19.2, C20.2, D1.1 (K), D2.1 (K), J1.A1B12 (GND), J1.B1A12 (GND), J1.S1 (SHELL), J1.S2 (SHELL), J1.S3 (SHELL), J1.S4 (SHELL), J3.S, J4.1, J4.3, R1.2, R4.2, RV1.3, RV2.3, S1.1, S2.1, U1.4 (GND), U1.9 (EP), U2.19 (TESTEN), U2.57 (GND), U3.1 (GND), U4.3 (VSS2), U4.10 (VSS3), U4.13 (EIO1), U4.15 (IS2), U4.27 (VSS1), U4.29 (EPAD), U5.2 (GND), U6.5 (GND), Y1.2
unnamed: C9.1, C10.1, C11.1, U2.23 (DVDD), U2.45 (VREG_VOUT), U2.50 (DVDD)
unnamed: C14.2, C15.2, U4.1 (VCAPS), U4.28 (VDD)
unnamed: C16.2, U4.11 (VCAPD)
unnamed: C17.2, U4.9 (VCAPA)
unnamed: D1.2 (A), R7.2
unnamed: D2.2 (A), R12.2
unnamed: D3.1 (K), R16.2, U6.2 (A)
unnamed: D3.2 (A), J2.T, U6.3 (C)
unnamed: J1.A5 (CC1), R4.1
unnamed: J1.B5 (CC2), R1.1
unnamed: J2.R, R16.1
unnamed: J3.R, R18.1
unnamed: J3.T, R17.1
unnamed: R5.2, U2.46 (USB_D-)
unnamed: R6.2, U2.47 (USB_D+)
unnamed: R8.2, U4.4 (RX0)
unnamed: R9.2, U4.5 (RX1)
unnamed: R10.2, U4.6 (RX2)
unnamed: R11.2, U4.7 (RX3)
unnamed: U1.2 (DO/IO1), U2.55 (QSPI_SD1)
unnamed: U1.3 (~WP/IO2), U2.54 (QSPI_SD2)
unnamed: U1.5 (DI/IO0), U2.53 (QSPI_SD0)
unnamed: U1.6 (SCK), U2.52 (QSPI_SCLK)
unnamed: U1.7 (~HOLD/IO3), U2.51 (QSPI_SD3)
unnamed: U2.20 (XIN), Y1.1
unnamed: U2.21 (XOUT), Y1.3
unnamed: U4.25 (TXD), U5.3 (IN)

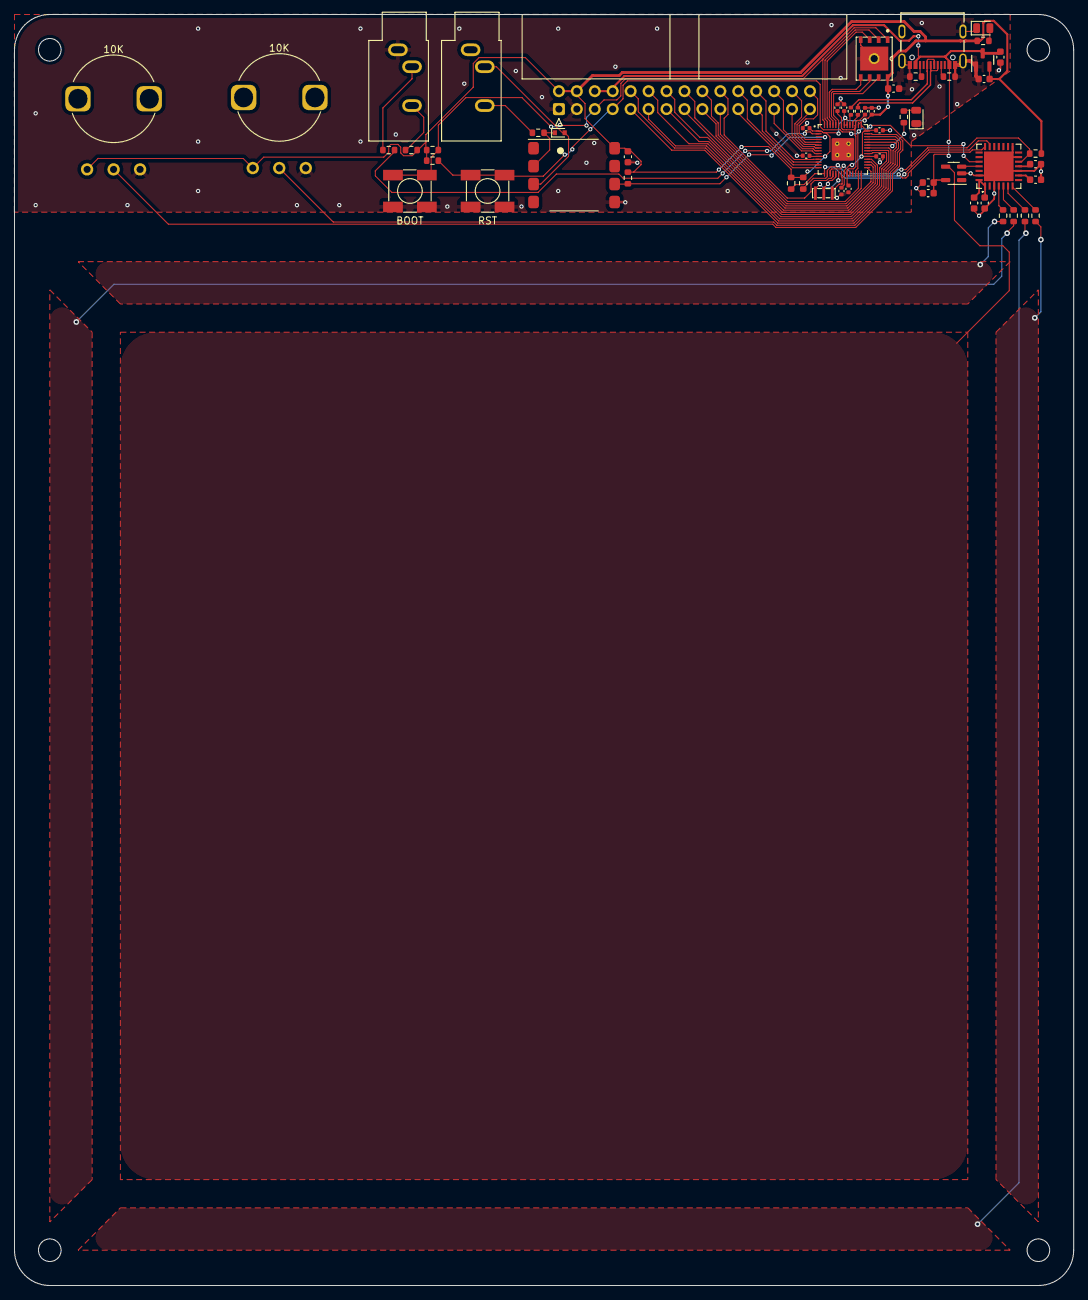
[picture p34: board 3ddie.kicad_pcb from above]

Board: 2 copper layers, 150.0 x 180.0 mm, 57 parts (0 on the bottom side), 64 nets.

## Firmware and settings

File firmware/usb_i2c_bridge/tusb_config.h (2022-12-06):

/*
 * The MIT License (MIT)
 *
 * Copyright (c) 2019 Ha Thach (tinyusb.org)
 *
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
 */

#ifndef _TUSB_CONFIG_H_
#define _TUSB_CONFIG_H_

#ifdef __cplusplus
extern "C" {
#endif

//--------------------------------------------------------------------
// COMMON CONFIGURATION
//--------------------------------------------------------------------

// defined by board.mk
#ifndef CFG_TUSB_MCU
#error CFG_TUSB_MCU must be defined
#endif

// RHPort number used for device can be defined by board.mk, default to port 0
#ifndef BOARD_DEVICE_RHPORT_NUM
#define BOARD_DEVICE_RHPORT_NUM 0
#endif

// RHPort max operational speed can defined by board.mk
// Default to Highspeed for MCU with internal HighSpeed PHY (can be port specific), otherwise FullSpeed
#ifndef BOARD_DEVICE_RHPORT_SPEED
#if (CFG_TUSB_MCU == OPT_MCU_LPC18XX || CFG_TUSB_MCU == OPT_MCU_LPC43XX || CFG_TUSB_MCU == OPT_MCU_MIMXRT10XX || CFG_TUSB_MCU == OPT_MCU_NUC505 || \
     CFG_TUSB_MCU == OPT_MCU_CXD56 || CFG_TUSB_MCU == OPT_MCU_SAMX7X)
#define BOARD_DEVICE_RHPORT_SPEED OPT_MODE_HIGH_SPEED
#else
#define BOARD_DEVICE_RHPORT_SPEED OPT_MODE_FULL_SPEED
#endif
#endif

// Device mode with rhport and speed defined by board.mk
#if BOARD_DEVICE_RHPORT_NUM == 0
#define CFG_TUSB_RHPORT0_MODE (OPT_MODE_DEVICE | BOARD_DEVICE_RHPORT_SPEED)
#elif BOARD_DEVICE_RHPORT_NUM == 1
#define CFG_TUSB_RHPORT1_MODE (OPT_MODE_DEVICE | BOARD_DEVICE_RHPORT_SPEED)
#else
#error "Incorrect RHPort configuration"
#endif

#ifndef CFG_TUSB_OS
#define CFG_TUSB_OS OPT_OS_NONE
#endif

// CFG_TUSB_DEBUG is defined by compiler in DEBUG build
// #define CFG_TUSB_DEBUG           0

/* USB DMA on some MCUs can only access a specific SRAM region with restriction on alignment.
 * Tinyusb use follows macros to declare transferring memory so that they can be put
 * into those specific section.
 * e.g
 * - CFG_TUSB_MEM SECTION : __attribute__ (( section(".usb_ram") ))
 * - CFG_TUSB_MEM_ALIGN   : __attribute__ ((aligned(4)))
 */
#ifndef CFG_TUSB_MEM_SECTION
#define CFG_TUSB_MEM_SECTION
#endif

#ifndef CFG_TUSB_MEM_ALIGN
#define CFG_TUSB_MEM_ALIGN __attribute__((aligned(4)))
#endif

//--------------------------------------------------------------------
// DEVICE CONFIGURATION
//--------------------------------------------------------------------

#ifndef CFG_TUD_ENDPOINT0_SIZE
#define CFG_TUD_ENDPOINT0_SIZE 64
#endif

//------------- CLASS -------------//
#define CFG_TUD_HID    0
#define CFG_TUD_CDC    1
#define CFG_TUD_MSC    0
#define CFG_TUD_MIDI   0
#define CFG_TUD_VENDOR 0

#define CFG_TUD_VENDOR_EPSIZE     32
#define CFG_TUD_VENDOR_EP_BUFSIZE 512
#define CFG_TUD_VENDOR_RX_BUFSIZE 512
#define CFG_TUD_VENDOR_TX_BUFSIZE 512

#define CFG_TUD_CDC_RX_BUFSIZE 512
#define CFG_TUD_CDC_TX_BUFSIZE 512

// HID buffer size Should be sufficient to hold ID (if any) + Data
#define CFG_TUD_HID_EP_BUFSIZE 16

// MSC Buffer size of Device Mass storage
#define CFG_TUD_MSC_EP_BUFSIZE 512

#define CFG_TUD_CDC_EP_BUFSIZE 512

#ifdef __cplusplus
}
#endif

#endif /* _TUSB_CONFIG_H_ */

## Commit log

2022-10-23 meeting 10/23/22 initial schema
    [3382g-001-xxx.stp, 3ddie.kicad_pcb, 3ddie.kicad_sch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]
2022-10-23 add .gitignore for kicad and ds_store
2022-10-23 fix MGC3130 symbol and footprint, update schema
    [3ddie.kicad_sch]
2022-10-25 In-class work 10/25
    [3ddie.kicad_sch]
2022-10-31 add electrode schematic symbol
2022-10-31 connect electrodes, fill in title block, annotate symbols
    [3ddie.kicad_sch]
2022-11-04 adding midi connectors and dac
    [3ddie.kicad_sch]
2022-11-08 Remove DAC, rename pins from schem review
    [3ddie.kicad_sch]
2022-11-08 annotate symbols, add value to optocoupler bypass cap
    [3ddie.kicad_sch]
2022-11-08 update component value formatting for consistency
    [3ddie.kicad_sch]
2022-11-08 fix symbol annotations
    [3ddie.kicad_sch]
2022-11-08 add datasheet links, part numbers, and catalog numbers to symbols
    [3ddie.kicad_sch]
2022-11-08 specify optocoupler diode, assign some footprints
    [3ddie.kicad_sch]
2022-11-08 continue adding footprints
    [3ddie.kicad_sch]
2022-11-08 create footprint for 6N137 according to datasheet
2022-11-08 finish assigning footprints (other than electrodes)
    [3ddie.kicad_sch]
2022-11-12 add bypass caps to level shifter, start mgc portion of layout
    [3ddie.kicad_pcb, 3ddie.kicad_sch]
2022-11-12 fill in pcb title block
    [3ddie.kicad_pcb]
2022-11-14 switch to through hole mounting trs jacks
    [3ddie.kicad_pcb, 3ddie.kicad_sch]
2022-11-15 Adding pots, pin sockets, and footprints
    [3ddie.kicad_sch]
2022-11-15 move eclectronics library into project directory
    [3382g-001-xxx.stp, ABM10.STP, ABS06-107.STP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]
2022-11-15 get 3d model for 3.5mm jack
    [CUI_DEVICES_SJ1-3533NG.igs]
2022-11-15 continue layout
    [3ddie.kicad_pcb, 3ddie.kicad_sch]
2022-11-16 expand board outline, add dimensions
    [3ddie.kicad_pcb]
2022-11-16 fix potentiometer footprint
2022-11-16 add 3d model to MGC3130 footprint
    [QFN28_5X5MQ_MCH.step]
2022-11-16 continued routing
    [3ddie.kicad_pcb, 3ddie.kicad_sch]
2022-11-17 layout and schema changes
    [3ddie.kicad_pcb, 3ddie.kicad_sch]
2022-11-18 fix mgc footprint courtyard
2022-11-18 mostly finish routing and layout!
    [3ddie.kicad_pcb, 3ddie.kicad_sch]
2022-11-18 rename symbol library to match project name, fix eclectronics lib path
    [6N137SDM.stp, CUI_DEVICES_SJ1-3533NG.igs, QFN28_5X5MQ_MCH.step]
2022-11-18 add silkscreen images
2022-11-18 clean up routing, add debug header, add silkscreen
    [3ddie.kicad_sch]
2022-11-18 add date (nov 2022) to board
2022-11-18 fill in missing part numbers for bom prep
    [3ddie.kicad_sch]
2022-11-18 exclude debug header from bom
    [3ddie.kicad_sch]
2022-11-18 fix incorrect part numbers for buttons
    [3ddie.kicad_sch]
2022-11-18 add bom
    [3ddie-bom-cleaned.csv]
2022-12-01 replace incorrectly sized MGC3130 footprint with correct one, adjust schema and pcb accordingly
    [3ddie.kicad_sch]
2022-12-01 swap 6n137 footprint for correct one, fix duplicate lines in mgc footprint, adjust layout
    [3ddie.kicad_sch]
2022-12-01 fix MCLR line being connected to run, adjust routing
    [3ddie.kicad_sch]
2022-12-01 fix mgc pin 1 indicator and 3d model
2022-12-01 add 3d model to mgc footprint in library
2022-12-01 update version number and date in title blocks
    [3ddie.kicad_sch]
2022-12-01 update solder paste layer for mgc
2022-12-02 add 3d model for potentiometer
    [PDB12-H4251-103PF.iges]
2022-12-03 set grid origin, change potentiometer 3d model from .iges to .step
    [PDB12-H4251-103PF.iges, PDB12-H4251-103PF.step]
2022-12-03 untrack .kicad_prl settings file
2022-12-03 change TRS jack 3d model from .igs to .step
    [CUI_DEVICES_SJ1-3533NG.igs, CUI_DEVICES_SJ1-3533NG.step]
2022-12-03 repair and add color to button 3d model
    [TL3301AFxxxxJ.stp]
2022-12-03 fix usb c connector color
    [USB4105-GF-A.step]
2022-12-06 move usb i2c bridge stuff into it's own subfolder
2022-12-06 add modified rp2040-i2c-interface as base for bridge
2022-12-06 modify tinyusb configuration to be CDC driver
2022-12-07 shrink mgc exposed pad paste, add drill origin
2022-12-07 add solidworks assembly for case design
2023-11-20 add header footprint
    [10112684-G03-06ULFc.igs]

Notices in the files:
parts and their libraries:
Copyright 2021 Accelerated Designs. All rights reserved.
